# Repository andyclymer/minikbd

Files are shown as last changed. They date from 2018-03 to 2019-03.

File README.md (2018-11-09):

# MiniKbd

The MiniKbd is a USB device based on the [Adafruit Trinket M0](https://learn.adafruit.com/adafruit-trinket-m0-circuitpython-arduino) development board which is programmable with CircuitPython. The parts are [available for sale on Tindie](https://www.tindie.com/products/andyclymer/minikbd-little-diy-mechanical-keyboard-kit/), with build documentation and software samples available in this repo.

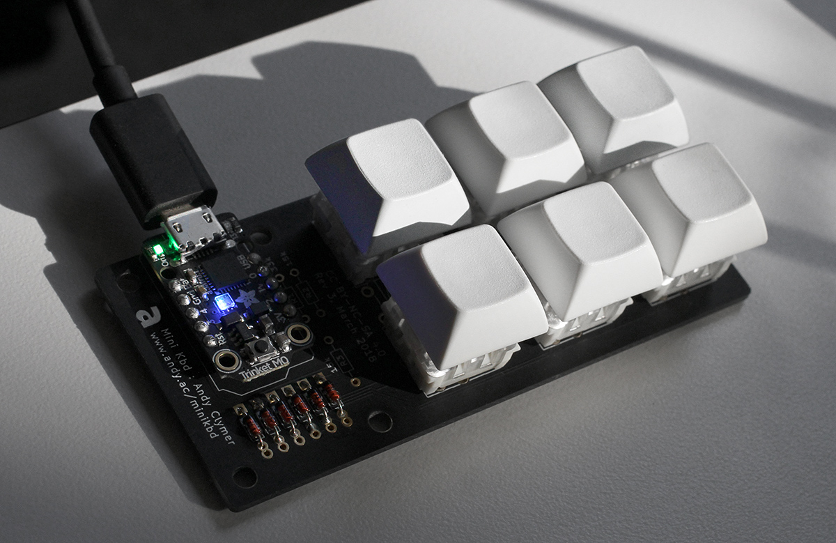
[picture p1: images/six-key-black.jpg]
MiniKbd


The MiniKbd is programmable with CircuitPython, each key can be easily customized to perform any combination of keystroke or mouse movement. When plugging it in over USB, your computer will recognize it as a “USB HID” (Human Interface Device), as if a keyboard or mouse had been plugged in. The keystrokes that are output by the MiniKbd can then be configured by editing the CircuitPython code running on the device.

The project came out of the idea of wanting a keyboard that simply had a larger set of arrow keys that I could position to the left side of my keyboard. [OSH Park](http://www.oshpark.com), the prototyping service that I use  to manufacture PCBs will always make boards in sets of three, so instead of having three of the same device I designed the MiniKbd to be built in three separate ways —

# Documentation and parts list

The MiniKbd is a DIY project, and I hope that you'll build one! Complete build documentation, parts list, and KiCad source files can be found in the [Hardware](./Hardware) directory of this repo, and code examples can be found inthe [Software](./Software) directory.

## Buying it
[The MiniKbd kit is available for sale on Tindie](https://www.tindie.com/products/andyclymer/minikbd-little-diy-mechanical-keyboard-kit/) if you'd like to build one (or two) for yourself!



# Build the MiniKbd in one of three layouts

[The build documentation can be found in the Hardware directory of this repo.](./Hardware)

### Layout #1: “Six Keyboard Keyswitches”

Six keyboard keys, with component footprints for the most popular Cherry MX, Cherry ML and Kalih Low Profile keyswitches. Choose keyswitches that are as clicky and springy as you wish.

Since the Trinket M0 only has five general purpose IO pins and this variation has six keyswitches, they are wired up as a matrix of three rows by two columns of keyswitches. I've written a simple library to read the keypresses of a small [button matrix](https://github.com/andyclymer/circuitpython_libs/tree/master/buttonMatrix) like this one.

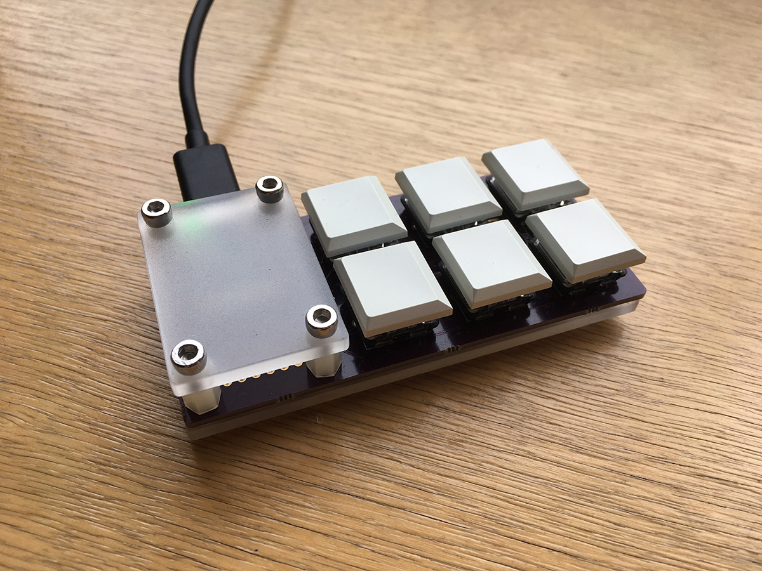
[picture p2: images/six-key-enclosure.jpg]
MiniKbd with six keyswitches


### Layout #2: “Two Rotary Encoders”

Whereas a “potentiometer” is the kind of knob designed to turn from 0 to 100% (like a volumne knob), its cousin the Rotary Encoder can freely turn continuously in either direction, clicking like a jog-dial as it turns (usually 12 or 24 clicks per rotation). With each click, the MiniKbd receives a signal that it's able to interpret to know whether it was turned clockwise or counterclockwise. Then, with each click, a keyboard command can be sent to the computer.

For instance, if the "z" and "x" keys are set up to zoom in and out in your drawing application, you can make one of the encoders into a zoom knob by having it type the letter "z" with each click in one direction, and the letter "x" in the other. 

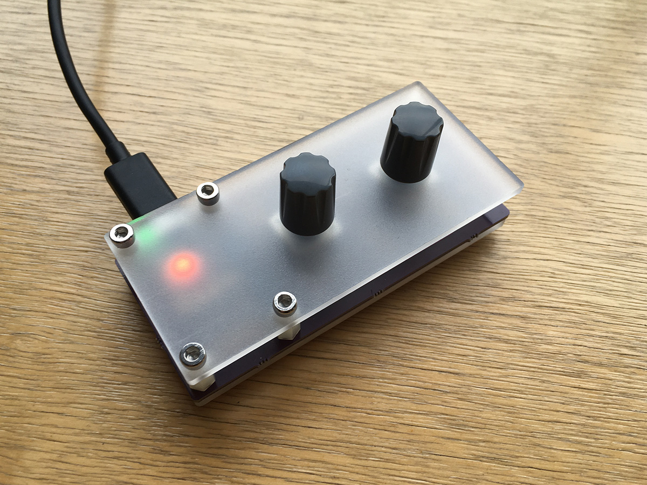
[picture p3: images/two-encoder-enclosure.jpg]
MiniKbd with two encoders

### Layout #3: “One rotary encoder and two keyboard keyswitches”

The best of both worlds, almost like a little mouse that only has a scroll wheel and two buttons for clicking.

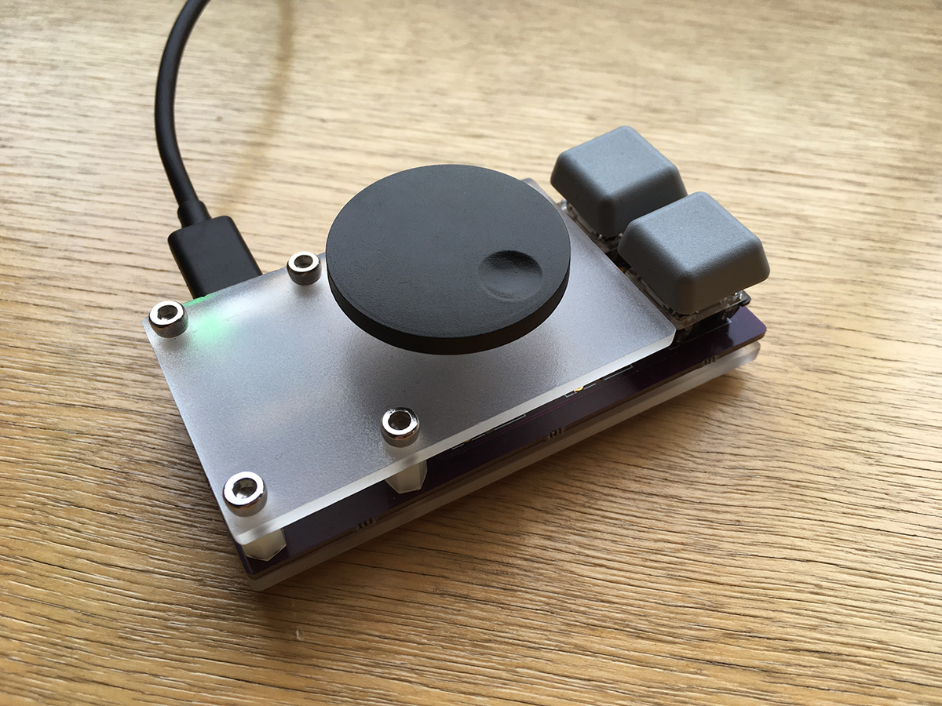
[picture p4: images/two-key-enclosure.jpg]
MiniKbd with one encoder and two keys


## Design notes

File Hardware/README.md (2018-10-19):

# MiniKbd Hardware

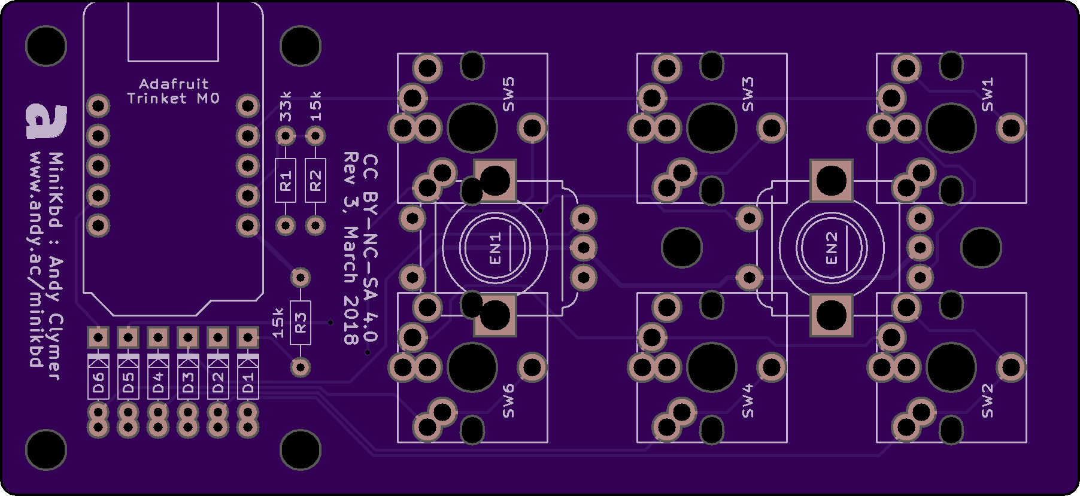
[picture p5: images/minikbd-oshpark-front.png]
minikbd-oshpark-front


The MiniKbd is designed to be built in one of three configurations:

- “Six keyboard keyswitches”
- “Two rotary encoders”
- “One rotary encoder and two keyboard keyswitches”

## Buying it
[The MiniKbd kit is available for sale on Tindie](https://www.tindie.com/products/andyclymer/minikbd-little-diy-mechanical-keyboard-kit/) if you'd like to build one (or two) for yourself! I'm selling the PCB, four sticker feet, and an optional set of hardware for use with the enclosure. The remaining parts will need to be sourced separately, but they can be found fairly easily from my guide below.

## Parts List
The full list of parts for each of the three configurations along with a buying guide can be found in the [Parts List](./PartsList.md) file in this directory.

## Building it
Build guides are available for all three configurations:
- [Build Doc — Six Keyboard Keyswitches](./Build-SixKeyswitches.md)
- [Build Doc — Two Rotary Encoders](./Build-TwoEncoders.md)
- [Build Doc — One Rotary Encoder and Two Keyboard Keyswitches](./Build-OneEncoderTwoSwitches.md)

## MiniKbd Enclosure
A very simple laser cut enclosure can be made with the plans in the [Enclosure](./Enclosure) directory. Files are available to send for laser cutting at Ponoko if you don't have access to your own laser cutter.

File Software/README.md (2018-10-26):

# MiniKbd Software

When you connect the MiniKbd (or rather, the Adafruit Trinket M0) to your computer you'll find that it mounts as a small ``CIRCUITPY`` drive. Each time the Trinket M0 is powered up or restarted it will run the ``main.py`` that it finds at the root level of its file system, so all of your code editing will start with this file. I've included a few preset Python scripts in this area of the repo that you can drop in and start using.

The Trinket M0 is a full 32-bit computer, but resources are scarce! With only 256k of storage, after embedding a slimmed down Python standard library there isn't much room left for your own code. If you don't think you'll need to use the MiniKbd on a Windows computer, you can also save some space by deleting the Windows driver from the Trinket's drive.

## Sample code

Each of the directories in this part of the repo have sample code that you can drag and drop to the root level of the Trinket's file system. As soon as the new files show up, the device should reboot and it will be in use right away.

## Before editing

It might be really helpful to use the Terminal on your computer to connect to the device as a serial console, so that you can see any `print` statements and error messages while you work with the code on your MiniKBD. To do this, have a look at Adafruit's recommendation for [connecting to the serial console](https://learn.adafruit.com/welcome-to-circuitpython/advanced-serial-console-on-mac-and-linux).

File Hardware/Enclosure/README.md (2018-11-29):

## Enclosure

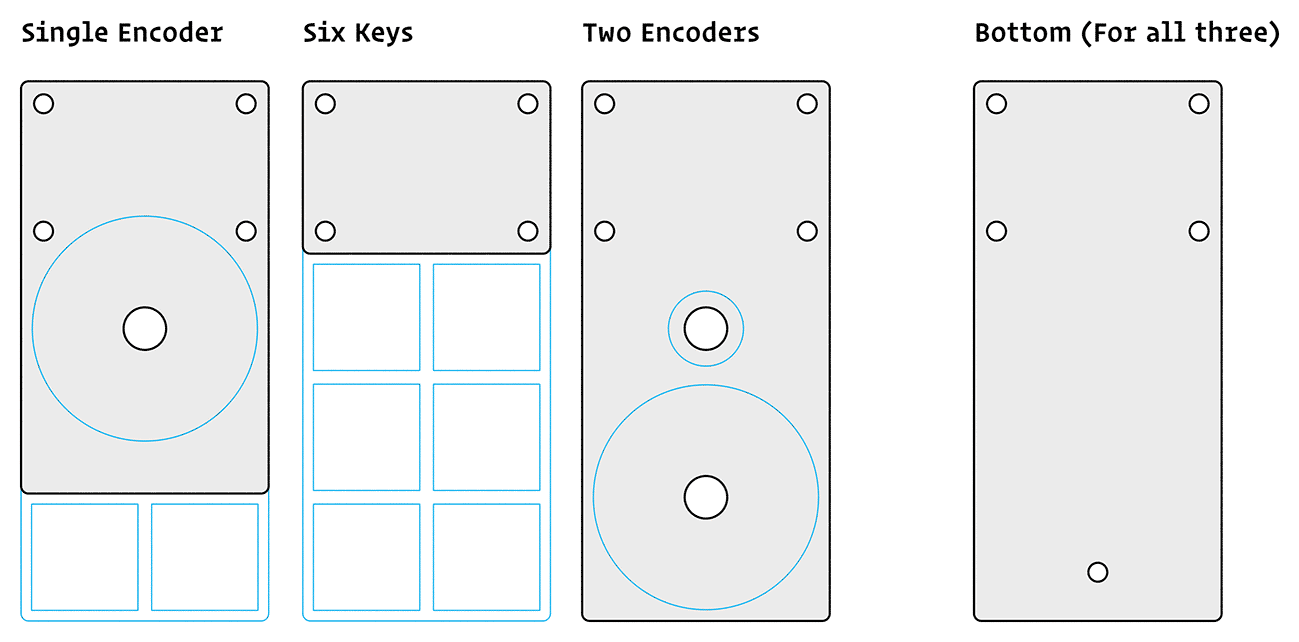
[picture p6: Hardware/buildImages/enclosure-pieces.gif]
enclosure


The MiniKbd doesn't need to be built in an enclosure, but at minumum I would highly suggest at least getting a set of small rubber bumper feet for the bottom so that it stays put and doesn't scratch up your desk. [Adafruit has a set of four](https://www.adafruit.com/product/550) if you're already ordering from them, as well as [Kiwi Electronics](https://www.kiwi-electronics.nl/siliconen-voetjes-voor-behuizingen-4-stuks) in The Netherlands, but I prefer the [3M SJ5312 Bumpon](https://www.amazon.com/gp/product/B000NG60SW/ref=oh_aui_detailpage_o00_s00?ie=UTF8&psc=1) because they're very small and grippy.

For the enclosure, I've laser cut parts in 1/8 inch (3mm) acrylic sheet, which can be avaialble from many sources. Files are available this directory, in the [Laser.pdf](./Laser.pdf). You won't want to completely obscure the LEDs on the top of the Trinket so I would recommend translucent acrylic if available. I like using the [Frosted Satin Ice](https://www.canalplastic.com/collections/plexi-sheets/products/0d010-df-frosted-satin-ice-acrylic-sheet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) that I buy at Canal Plastics in NYC, but I would encourage you to look for local options. 

Files are also prepared in this directory using templates from [Ponoko](https://www.ponoko.com/) where the enclosures can be ordered very cheaply. The files fit Ponoko’s smallest “P1” material size but the enclosure still only needs a small amount of material, feel free toa add your own art to the file before ordering.

In addition to the laser cut acrylic parts and the rubber bumper feet, you will also need:
- 4 × 8mm long M3 sized standoffs
- 5 × M3x8mm or 10mm screws
- 4 × M3x6mm screws
- 1 × M3 nut
- 5 × M3x1mm washers

Amazon and Ebay seem to be good places to buy these parts resonable price, I bought the [white Nylon m3 standoff assortment](https://www.amazon.com/gp/product/B01DK3905Y/ref=oh_aui_detailpage_o00_s00?ie=UTF8&psc=1) which is also available in [black](https://www.amazon.com/gp/product/B01E8JZWZ6/ref=ox_sc_sfl_title_14?ie=UTF8&psc=1&smid=A1Z1DJFHECM1GS), along with a small set of [M3 1mm nylon washers](https://www.amazon.com/gp/product/B01N45UFLG/ref=oh_aui_detailpage_o01_s00?ie=UTF8&psc=1). You can go nuts and get the same [stainless hex screws](https://www.amazon.com/gp/product/B01M3SFIAZ/ref=oh_aui_detailpage_o01_s00?ie=UTF8&psc=1) that I used for the top four screws of the enclosure.

The set of nylon hardware that I've linked to above only has 10mm long screws which will be too long, but you can very easily clip 2mm or so off of the screws that you use on the top of the enclosure.

### Build guide

#### 1)

Start with the bottom piece of the enclosure. Feed the five longer screws through, and temporarily cover the screw heads with tape.

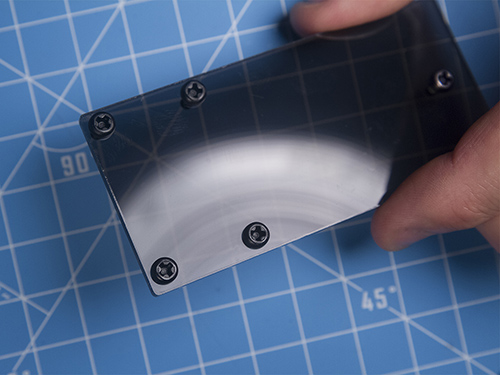
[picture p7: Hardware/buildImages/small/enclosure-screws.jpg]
Enclosure

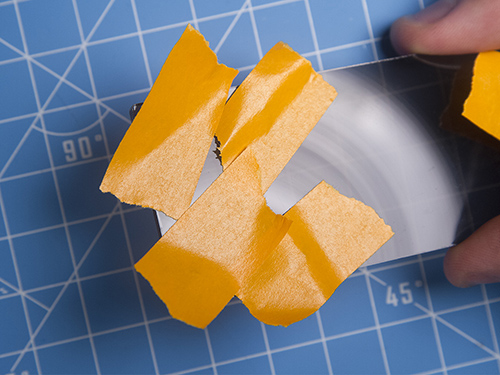
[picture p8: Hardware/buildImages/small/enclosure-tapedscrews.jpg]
Enclosure


#### 2)

Flip the bottom over so that the tape and screw heads are facing down (good thing the tape is holding it all together for now).

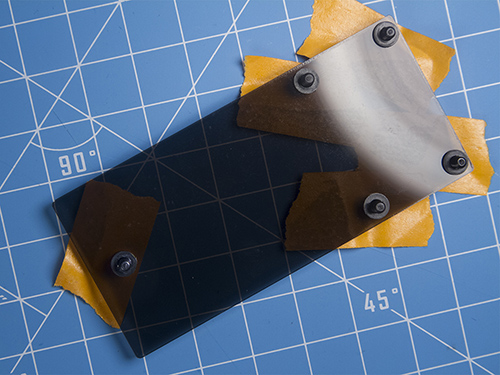
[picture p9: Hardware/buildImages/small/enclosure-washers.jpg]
Enclosure


Place the 1mm washers on all five screws. This will keep the MiniKbd circuit board spaced just slightly off of the enclosure, which should be enough room for the solder joints on the bottom of the board to keep from pressing down unevenly.

#### 3)

Keeping everything together, feed the MiniKbd circuit board on to the five screws and washers.

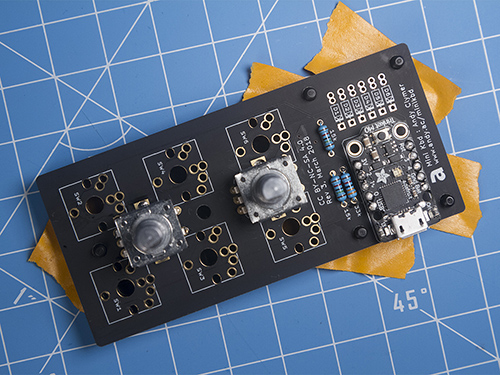
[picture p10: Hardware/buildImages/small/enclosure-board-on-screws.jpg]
Enclosure


#### 5)

Screw on the four spacers. You can start by tightening them by hand, then once the screw is started you can remove the tape and finish with a screwdriver. No need to over-tighten!

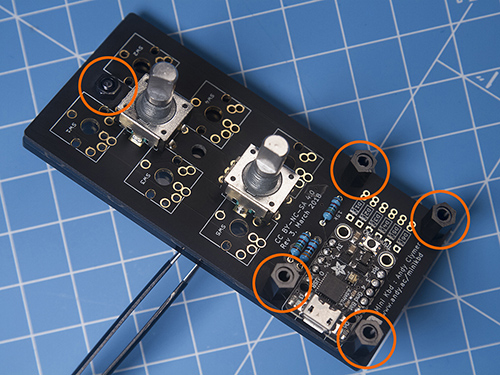
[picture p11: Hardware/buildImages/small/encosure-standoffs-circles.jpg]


Attach the nut to the fifth screw on the other end of the board. You might need a set of pliers to hold the nut while you attach the screw, or you might be able to just hold the nut by presing straight down with a finger.

#### 7)

Finish by attaching the top enclosure piece with four shorter screws.

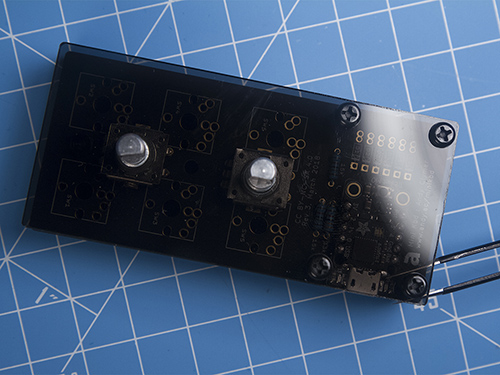
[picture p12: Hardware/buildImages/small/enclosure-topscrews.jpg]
Enclosure


Here's what the full stackup should look like:

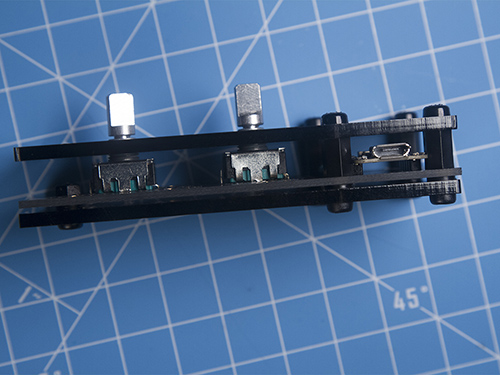
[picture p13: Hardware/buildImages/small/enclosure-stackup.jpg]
Enclosure


#### 8)

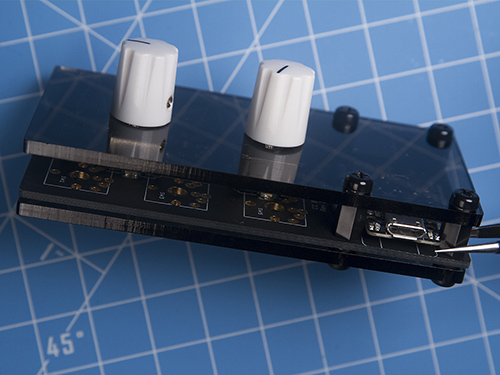
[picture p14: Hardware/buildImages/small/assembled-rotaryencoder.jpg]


Add the knobs or keycaps (depending on the build), and the sticker feet to the bottom of the MiniKbd and you're ready to go!

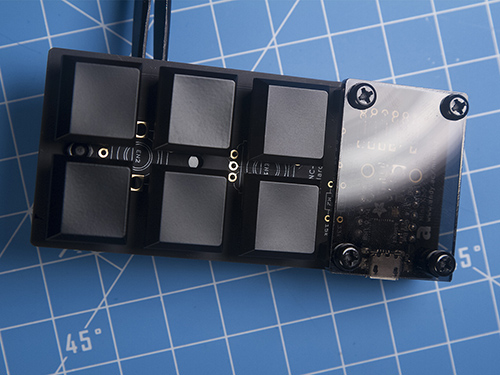
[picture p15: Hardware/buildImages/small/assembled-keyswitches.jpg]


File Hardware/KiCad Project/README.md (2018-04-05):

# MiniKbd Hardware

minikbd-oshpark-front

The MiniKbd is designed to be built in one of three configurations:

- “Six keyboard keyswitches”
- “Two rotary encoders”
- “One rotary encoder and two keyboard keyswitches”

## Buying it
Build one yourself! A batch of MiniKbd circuit boards is currently being made and once they've arrived in mid-April I'll have some for sale for around $6 each. Then, you can collect the parts listed below and build your own (or all three!)

## Parts List
Since there's more than one way to build the MiniKbd, not all component footprints on the MiniKbd PCB need to be filled depending on the variation you choose to build. Here are the parts lists for all three versions:

#### “Six Keyboard Keyswitches”
Qty | Component | Note
:---:|---|---
1 | Adafruit Trinket M0 | *The black “M0” and not the blue “3V” or “5V” variations of the Trinket*
6 | Keyswitches and keycaps | *Cherry MX, Cherry ML or Kailh Low Profile keyswitches will work*
6 | 1N4148 Small Signal Diodes | 
— | Various enclosure parts | *Optional but recommended, see notes below*

#### “Two Rotary Encoders”
Qty | Component | Note
:---:|---|---
1 | Adafruit Trinket M0 | *The black “M0” and not the blue “3V” or “5V” variations of the Trinket*
2 | Rotary Encoders | *2-bit quadrature, with a common footprint from the Bourns PEC11R series*
2 | 33kΩ Resistors | *1/8 watt*
1 | 15kΩ Resistors | *1/8 watt*
— | Various enclosure parts | *Optional but recommended, see notes below*

#### “One rotary encoder and two keyboard keyswitches”
Qty | Component | Note
:---:|---|---
1 | Adafruit Trinket M0 | *The black “M0” and not the blue “3V” or “5V” variations of the Trinket*
2 | Keyswitches and keycaps | *Cherry MX, Cherry ML or Kailh Low Profile keyswitches will work*
2 | 1N4148 Small Signal Diodes | 
1 | Rotary Encoder | *2-bit quadrature, with a common footprint from the Bourns PEC11R series*
— | Various enclosure parts | *Optional but recommended, see notes below*

## Buying Parts

#### Adafruit Trinket M0
The Trinket M0 can be purchased directly from the manufacturer, Adafruit, and can be found on other online shops for about $9 or €9. The most important consideration for this project is to buy the black colored Trinket “M0”, and *not* the blue “3V” or “5V” variations.

Retailer | Part number
---|---
Adafruit | Adafruit Trinket M0 [#3500](https://www.adafruit.com/product/3500)
Mouser | Adafruit Trinket M0 [485-3500](https://www.mouser.com/ProductDetail/Adafruit/3500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)
Floris | Adafruit Trinket M0 [#1947](https://www.floris.cc/shop/en/home/1947-adafruit-trinket-m0-for-use-with-circuitpython-arduino-ide.html)

#### Keyswitches and keycaps
There's an incredibly wide range of options when choosing keyswitches and keycaps, and the MiniKbd footprint works with the popular Cherry MX, Cherry ML and Kailh Low Profile keyswitches. Do a little bit of research first, the popular Cherry MX switches come in a wide array of options for [different levels of force or clickyness](http://www.keyboardco.com/blog/index.php/2012/12/an-introduction-to-cherry-mx-mechanical-switches/). I think the best advice I have is to order a few and see what you like. I prefer the [“Tactile Brown” Kailh Low Profile keyswitches from Novel Keys](https://novelkeys.xyz/products/kailh-low-profile-switches) and don't forget to order the [keycaps](https://novelkeys.xyz/collections/keycaps/products/kailh-low-profile-keycaps-blank). For the Cherry MX switches you have a wide range of options for keycaps from [Pimp My Keyboard](https://pimpmykeyboard.com/).

Retailer | Part number
---|---
Novel Keys | [Kailh Low Profile Keyswitches](https://novelkeys.xyz/products/kailh-low-profile-switches) and [Kailh Low Profile Keycaps](https://novelkeys.xyz/collections/keycaps/products/kailh-low-profile-keycaps-blank)
Mouser | [Cherry MX search results](https://www.mouser.com/Electromechanical/Switches/_/N-5g2h?Keyword=cherry+mx&FS=True) with lots of options

#### 1N4148 Small Signal Diodes
An extremely common part, one diode is required for each keyswitch.

Retailer | Part number
---|---
Adafruit | [#1641](https://www.adafruit.com/product/1641) for a 10 pack
Mouser | [512-1N4148](https://www.mouser.com/ProductDetail/ON-Semiconductor-Fairchild/1N4148?qs=sGAEpiMZZMudZehw8RjeZWbu6z6oTQTL)
Tayda Electronics | [A-157](https://www.taydaelectronics.com/1n4148-switching-signal-diode.html) for 1¢ each!

#### Rotary Encoders
You will need a standard *2-bit quadrature* encoder, which means that with each click as you rotate it will send a [pattern of pulses on two pins](https://en.wikipedia.org/wiki/Rotary_encoder) (and not a “gray code” encoder which uses three pins). I went with a common “footprint” for the rotary encoder which you would find in the Bourns PEC11R series, but not all encoders out there will fit. Any encoders with a lighted shaft would have extra pins that won't fit on the MiniKbd circuit board. Also note that the rotary encoders from Floris have the correct footprint, however the shaft would be too short to fit with the enclosure, but it would work fine without the enclosure top. 

Retailer | Part number
---|---
Adafruit | [#377](https://www.adafruit.com/product/377) comes with a simple knob
Mouser |  [PEC11R-4215F-S0024](https://www.mouser.com/ProductDetail/Bourns/PEC11R-4215F-S0024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)
Floris | [#567](https://www.floris.cc/shop/en/knobs-buttons-joysticks/567-rotary-encoder-.html?search_query=encoder&results=12) will work but will be too short for the enclosure

Also, don't forget to order a knob for the encoder, the recommended Bourns encoder would need a “D-shaft” knob.

Retailer | Part number
---|---
Adafruit | [#2055](https://www.adafruit.com/product/2055) is a larger 35mm knob, it won't sit flush with the enclosure but still looks nice
Thonk | [Davies 1900h clone D-shaft](https://www.thonk.co.uk/shop/1900h-d/)
DJ Tech Tools | [Chroma Caps](https://store.djtechtools.com/products/chroma-caps-knobs-and-faders)

#### Resistors
The “Two Encoders” build will need three resistors, but the two other builds won’t require any. The smaller and very common 1/8 Watt metal film resistors will fit nicely.

Retailer | Part number
---|---
Tayda Electronics | [A-3813](https://www.taydaelectronics.com/resistors/1-8w-metal-film-resistors/r-33k-ohm-1-8w-1-metal-film-resistor.html) for the 33k ohm (×2), and [A-3803](https://www.taydaelectronics.com/resistors/1-8w-metal-film-resistors/r-15k-ohm-1-8w-1-metal-film-resistor.html) for the 15k ohm (×1)
Mouser | **TK**

#### Enclosure parts

The enclosure consists of a variety of pieces, all of which are optional or can be substituted:
- Laser cut parts from acrylic sheet
- 4 × 8mm long M3 sized standoffs (5 or 6mm long should work)
- 9 × M3x6mm screws
- 1 × M3 nut
- 5 × M3x1mm washers
- 4 × rubber bumper feet

The MiniKbd doesn't need to be built in an enclosure, but at minumum I would highly suggest at least getting a set of small rubber bumper feet for the bottom so that it stays put and doesn't scratch up your desk. [Adafruit has a set of four](https://www.adafruit.com/product/550) if you're already ordering from them, but I prefer the [3M SJ5312 Bumpon](https://www.amazon.com/gp/product/B000NG60SW/ref=oh_aui_detailpage_o00_s00?ie=UTF8&psc=1) because they're very small and grippy.

For the enclosure, I've laser cut parts in 1/8 inch (3mm) acrylic sheet, which can be avaialble from many sources. Files are available in the Enclosure folder of the repo. You won't want to completely obscure the LEDs on the top of the Trinket so I would recommend translucent acrylic if available. I like using the [Frosted Satin Ice](https://www.canalplastic.com/collections/plexi-sheets/products/0d010-df-frosted-satin-ice-acrylic-sheet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) that I buy at Canal Plastics in NYC, but I would encourage you to look for local options. Laser cutting might also be able to be ordered from [Ponoko](https://www.ponoko.com/).

Amazon and Ebay seem to be good places to buy a variety of standoffs and screws at a resonable price, I use the [white Nylon m3 standoff assortment](https://www.amazon.com/gp/product/B01DK3905Y/ref=oh_aui_detailpage_o00_s00?ie=UTF8&psc=1) which is also available in [black](https://www.amazon.com/gp/product/B01E8JZWZ6/ref=ox_sc_sfl_title_14?ie=UTF8&psc=1&smid=A1Z1DJFHECM1GS), along with a small set of [M3 1mm nylon washers](https://www.amazon.com/gp/product/B01N45UFLG/ref=oh_aui_detailpage_o01_s00?ie=UTF8&psc=1). You can go nuts and get the same [stainless hex screws](https://www.amazon.com/gp/product/B01M3SFIAZ/ref=oh_aui_detailpage_o01_s00?ie=UTF8&psc=1) that I used for the top four screws of the enclosure.

## Building it
*Working on a build guide!*

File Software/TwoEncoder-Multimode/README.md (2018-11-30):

# MiniKbd Software — Multimode

This demo shows one way to use the Two Encoder build of the MiniKbd in more than one mode.

A more detailed breakdown of how the Two Encoder code works can be found with the TwoEncoder-Keyboard example, I would recommend becoming familiar with that demo first.

Pressing the left encoder button switches between modes. Each mode lights the RGB LED in a different color, and the callbacks are then written to fire off different keyboard combinations depending on the mode.

In this example, the first mode lights the LED greenish-blue and makes the encoder dials work as audio controls. The second mode lights the LED red and changes the encoders to work as shortcuts for a separate application.

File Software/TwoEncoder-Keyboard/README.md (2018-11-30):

# MiniKbd Software — Two Encoder Keyboard

This is the basic starting point for using two rotatry encoders as a keyboard.

As the rotary encoders turn, each click of the encoder triggers a keyboard command. This is really useful for the kinds of keystrokes that you might normally click repeatedly — the default here has one encoder typing "z" in one direction and "x" in the other which already map to the "Zoom In" and "Zoom Out" commands in the design application that I use. Instant zoom dial. Another idea could be to type the keyboard command for "Volume Up" with each click in one direction and "Volume Down" in another direction, I've provided this as a separate example in the same repo.

### How to use this sample code

Copy the `main.py` and `encoder.py` to the root level of your Trinket M0. The `main.py` code is run every time the Trinket reboots, and it imports code from the `encoder` library.

Before editing, I have some general advice for working with the MiniKBD one level back in the [Software](../) directory of this repo.

The `main.py` script contains the code that you'll edit to customize how the device works. Space is limited on the Trinket M0 so I'm providing a commented version of the code here to explain how it works (the comments would take up valuable space that you should be using for your code!)

```python
import board
import adafruit_dotstar as dotstar
from adafruit_hid.keyboard import Keyboard
from adafruit_hid.keycode import Keycode
from digitalio import DigitalInOut, Direction, Pull
from analogio import AnalogIn
import time
import random

# Import the encoder library that I've provided
from encoder import Encoder

# Create an object for the RGB "Dotstar" LED on the Trinket
# and set the RGB value for Black, to get started.
dot = dotstar.DotStar(board.APA102_SCK, board.APA102_MOSI, 1, brightness=0.1)
dot[0] = (0, 0, 0)

# Create a new Keyboard object. We'll send keyboard commands to this later.
kbd = Keyboard()

# Add a small 1/10 sec delay between button presses, otherwise clicking the encoder button might hit the callback several times
# This function will be checked before the button callback sends a keycode to the computer.
prevTurn = time.monotonic()
def fastClick():
	global prevTurn
	now = time.monotonic()
	diff = now - prevTurn
	prevTurn = now
	if diff < 0.1:
		return True
	return False

# Encoder callbacks

# Each time the rotary encoder moves one notch "up" or one notch "down" these functions are called
# You'll edit these: replace the print statements with whatever you want the device to do when
# the rotary encdoer is rotated.

# Customize the keycodes to change how the device functions.
# Each key has a number, and one keycode. The full list of keycodes can be found here:
# https://circuitpython.readthedocs.io/projects/hid/en/latest/api.html#adafruit-hid-keycode-keycode

# The first encoder will type the letter "z" with each click when rotated in one direction,
# and the letter "x" when rotated in the other direction. In the design appliaction I use,
# these two keystrokes will zoom in and zoom out of the document. Nice!
# They also set the LED to be a random reddish color when rotated in one direction, and a
# random blueish color in the other direction.

def enc1Up():
	print("enc-1-up")
	dot[0] = (255, random.randint(0, 255), 0)
	kbd.press(Keycode.Z)
	kbd.release_all()
	
def enc1Down():
	print("enc-1-down")
	dot[0] = (0, random.randint(0, 255), 255)
	kbd.press(Keycode.X)
	kbd.release_all()

# Then, the other encoder types the left bracket when rotated in one direction, and the right bracket
# when rotated the other direction. Again, in the application I use, these step up and down through
# the drawing layers. Between these two encoders I have a nice little interface!

def enc2Up():
	print("enc-2-up")
	dot[0] = (255, random.randint(0, 255), 0)
	kbd.press(Keycode.LEFT_BRACKET)
	kbd.release_all()

def enc2Down():
	print("enc-2-down")
	dot[0] = (0, random.randint(0, 255), 255)
	kbd.press(Keycode.RIGHT_BRACKET)
	kbd.release_all()

# The encoders also work like buttons when they're pressed down. The first encoeder (the one that was
# zooming in and out for me) will type Command-Zero which resets the zoom to 100%. The other
# encoder types Command-A when clicked down.
# Before returning the keycode, it calls the fastClick() function which will return True if 
# the button had been pressed down 1/10 sec previously.

def button1():
	if not fastClick():
		print("enc-1-button")
		# Press a combination of the command key and zero
		kbd.press(Keycode.GUI, Keycode.ZERO)
		kbd.release_all()
	
def button2():
	if not fastClick():
		print("enc-2-button")
		kbd.press(Keycode.GUI, Keycode.A)
		kbd.release_all()

# Make a new objects for the rotary encoders. These take care of watching for changes in state
# to the encoder, it figures out if the encoder was rotating "up" or "down", and then calls
# the callback functions above.

e1 = Encoder(board.D4, board.D3, upCallback=enc1Up, downCallback=enc1Down)
e2 = Encoder(board.D1, board.D0, upCallback=enc2Up, downCallback=enc2Down)

# The two encoders have buttons when they're clicked down, and they share an analog input pin.
# This will be explained a little bit more below.
buttonPin = AnalogIn(board.D2)

# The main loop for the script. Now that all of the callback functions are defined, and the
# objects are made, this script will continuously ask the Encoder objects to update and check
# for a state change. When the state does change, the objects will call the callback functions 
# at the top of this script.

while True:
	
  # Check both encoders for a change
	e1.update()
	e2.update()
	
	# The two encoder buttons share one analog input pin (because only one pin is left!)
	# The buttons pass through resistors of different values, so buy comparing the analog
	# voltage we're able to see which buttons are being held down.
	v = buttonPin.value
	if 65535 > v > 54500:
		b1 = False
		b2 = False
	elif 54500 > v > 38500:
		b1 = True
		b2 = False
	elif 38500 > v > 29400:
		b1 = False
		b2 = True
	elif v < 29400:
		b1 = True
		b2 = True
    
	# Now that we know which buttons are held down, call their callback functions
	if b1:
		button1()
	if b2:
		button2()

```

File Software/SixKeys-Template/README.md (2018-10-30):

# MiniKbd Software — Six Keyswitches

This is the simplest way to get started with the "Six Keyswitches" build, it provides an easy way to assign a single keystroke to each key. Other more complex examples are also available.

### How to use this sample code

Copy the `main.py` and `buttonMatrix.py` to the root level of your Trinket M0. The `main.py` code is run every time the Trinket reboots, and it imports code from the `buttonMatrix` library.

Before editing, I have some general advice for working with the MiniKBD one level back in the [Software](../) directory of this repo.

The basic principle is that you will want to edit the `buttonIDtoKeycode` dictionary in the `main.py` to customize the keyboard.

```python
buttonIDtoKeycode = {
    1: Keycode.SHIFT,
    2: Keycode.RIGHT_ARROW,
    3: Keycode.UP_ARROW,
    4: Keycode.DOWN_ARROW,
    5: Keycode.SHIFT,
    6: Keycode.LEFT_ARROW}
 ```
Each key is assigned a keycode in this dictionary. A full list of keycodes can be found in the [CircuitPython keycode docs](https://circuitpython.readthedocs.io/projects/hid/en/latest/api.html). When looking directly at the keyboard, the keys are numbered in the following arrangement:
 
 ```
 ┏━┷┷━┯━━━┯━━━┯━━━┓
 ┃°  °│ 5 │ 3 │ 1 ┃
 ┃    ├───┼───┼───┨
 ┃°  °│ 6 │ 4 │ 2 ┃
 ┗━━━━┷━━━┷━━━┷━━━┛
 
```

The `main.py` script contains the code that you'll edit to customize how the device works. Space is limited on the Trinket M0 so I'm providing a commented version of the code here to explain how it works (the comments would take up valuable space that you should be using for your code!)

```python
import board
from digitalio import DigitalInOut, Direction, Pull
import adafruit_dotstar as dotstar
from adafruit_hid.keyboard import Keyboard
from adafruit_hid.keycode import Keycode
from adafruit_hid.keyboard_layout_us import KeyboardLayoutUS

# Import the MiniKbdButtons library that I've provided
# All of the code that deals with reacting to key changes is kept in here
from miniKbdButtons import MiniKbdButtons

# Create an object for the RGB "Dotstar" LED on the Trinket
# and set the RGB value for Black, to get started.
dot = dotstar.DotStar(board.APA102_SCK, board.APA102_MOSI, 1, brightness=0.2)
dot[0] = (0, 0, 0)

# Create a new Keyboard object. We'll send keyboard commands to this later.
kbd = Keyboard()
kbdLayout = KeyboardLayoutUS(kbd)

# Customize these keycodes to change how the device functions.
# Each key has a number, and one keycode. The full list of keycodes can be found here:
# https://circuitpython.readthedocs.io/projects/hid/en/latest/api.html#adafruit-hid-keycode-keycode
buttonIDtoKeycode = {
	1: Keycode.ONE,
	2: Keycode.TWO,
	3: Keycode.THREE,
	4: Keycode.FOUR,
	5: Keycode.FIVE,
	6: Keycode.SIX}

# Key callbacks

# These functions are called when a key is pressed down and when a key is released.
# You'll edit these: replace the print statements with whatever you want the device to do when
# the keys are pressed or released.

# All of the buttons use the same callback functions, but the function receives the ID number of
# the key so you can program the callbacks to do different things depending on which key is held down.
# Another helpful thing is you'll also be given a list of othersDown which contains the button IDs
# for any other buttons that are also being held down.

# This simple example takes the buttonID and finds the keycode in the buttonIDtoKeycode dictionary
# (shown above) and then tells the keyboard object to press this keycode.

def buttonDownCallback(buttonID, othersDown):
    # When a key is pressed, find its keycode in the buttonIDtoKeycode dictionary,
    # and tell the keyboard object to press this keycode.
	kbd.press(buttonIDtoKeycode[buttonID])
	dot[0] = (255, 0, 0) # Turn the LED to be 100% Red and 0% Green and Blue
	print("Button _down_", buttonID, othersDown)

def buttonUpCallback(buttonID):
    # When a key has been lifted, find its keycode again in the buttonIDtoKeycode dictionary
    # and tell the keyboard to release that key. Without doing this, the key would still be held down!
	kbd.release(buttonIDtoKeycode[buttonID])
	dot[0] = (0, 0, 0)
	print("Button ^UPUP^", buttonID)

# Create a new MiniKbdButtons object, which we'll use in just a moment...
ButtonMatrix = MiniKbdButtons(
	keyDownCallback=buttonDownCallback, 
	keyUpCallback=buttonUpCallback)

# The main loop for the script. Now that all of the callback functions are defined, and the
# objects are made, this script will continuously ask the ButtonMatrix object to update and check
# for a state change. When the state does change, the objects will call the callback functions 
# at the top of this script.
while True:
	ButtonMatrix.update()
```

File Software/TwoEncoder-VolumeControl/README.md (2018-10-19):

# MiniKbd Software — Volume Control

For use with the “Two Rotary Encoders” build variation. One knob advances the track forward and back, the other knob adjusts the volume. This script builds off of the [TwoEncoderKeyboard](../TwoEncoderKeyboard) sample code.

On the Mac, turning the volume knob slowly increments the level with fine-grained control, the equivalent of holding down the “Option” key while pressing the volume keys on the keyboard. A quick turn increments the volume at a faster rate.

Pressing either knob will send the “Play/Pause” keystroke.

### How to use this sample code

Copy the `main.py` and `encoder.py` to the root level of your Trinket M0. The `main.py` code is run every time the Trinket reboots, and it imports code from the `encoder` library.

Before editing, I have some general advice for working with the MiniKBD one level back in the [Software](../) directory of this repo.

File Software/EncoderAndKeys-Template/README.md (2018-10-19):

# MiniKbd Software — One Encoder and Two Keys

This is the basic starting point for code that works with the build option of one rotary encoder and two keyboard keys.

### How to use this sample code

Copy the `main.py`, `encoder.py` and `buttonMatrix.py` to the root level of your Trinket M0. The `main.py` code is run every time the Trinket reboots, and it imports code from the `encoder` and `buttonMatrix` libraries.

Before editing, I have some general advice for working with the MiniKBD one level back in the [Software](../) directory of this repo.

The `main.py` script contains the code that you'll edit to customize how the device works. Space is limited on the Trinket M0 so I'm providing a commented version of the code here to explain how it works (the comments would take up valuable space that you should be using for your code!)

```python
import board

# Import the Encoder and ButtonMatrix libraries that I've provided
from encoder import Encoder
from buttonMatrix import ButtonMatrix

# Encoder callbacks
# Each time the rotary encoder moves one notch "up" or one notch "down" these functions are called
# You'll edit these: replace the print statements with whatever you want the device to do when
# the rotary encdoer is rotated.

def rotatedUp():
	print("Up!")

def rotatedDown():
	print("Down!")

# Key callbacks
# These functions are called when a key is pressed down, 
# when a key is released, and when a key is held down for a length of time.
# You'll edit these: replace the print statements with whatever you want the device to do when
# the keys are pressed or released.
#   An info dictionary is passed along with it, with some helpful data:
#     'buttonID' = 1 or 2, the key number
#     'repeating' = True/False
#     'holdTime' = How long the key has been held down for
#     'othersDown' = A list of other buttonIDs that were already held down when this one was pressed

def buttonDownCallback(info):
	print("Button %s down" % info["buttonID"])

def buttonUpCallback(info):
	print("Button %s down" % info["buttonID"])

def buttonHoldCallback(info):
	print("Button %s down" % info["buttonID"])

# In the "One Encoder and Two Keyboard Keys" build setup, key number 1 is connected to
# pins D0 and D2, and key number 2 is connected to pins D1 and D2. They're wired in a matrix: 
# a signal is applied to both keys through D2 and the MiniKBD can sense which key(s) are held 
# down by checkingthe inputs of D0 and D1.

buttonMap = [
	dict(sendPinName="D0", receivePinName="D2", buttonID=1),
	dict(sendPinName="D1", receivePinName="D2", buttonID=2)]

# Make a new ButtonMatrix object for these two keys. This takes care of checking the state of 
# the keys and it will call the button callback functions above when the state changes.

Matrix = ButtonMatrix(
	buttonMap, 
	keyDownCallback=buttonDownCallback,
	keyUpCallback=buttonUpCallback,
	keyHoldCallback=buttonHoldCallback,
	holdDelayTime=1,
	holdRepeatTime=0.1)

# Make a new object for the rotary encoder. This takes care of watching for changes in state
# to the encoder, it figures out if the encoder was rotating "up" or "down", and then calls
# the callback functions above.

Encoder = Encoder(board.D3, board.D4, upCallback=rotatedUp, downCallback=rotatedDown)

# The main loop for the script. Now that all of the callback functions are defined, and the
# objects are made, this script will continuously ask the Encoder and Matrix objects to update
# and check for a state change. When the state does change, the objects will call the callback
# functions at the top of this script.

while True:
	Encoder.update()
	Matrix.update()
  
  ```

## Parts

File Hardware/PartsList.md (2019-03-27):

# MiniKbd Parts List

Since there's more than one way to build the MiniKbd, not all component footprints on the MiniKbd PCB need to be filled depending on the variation you choose to build. Here are the parts lists for all three versions:

#### “Six Keyboard Keyswitches”
Qty | Component | Note
:---:|---|---
1 | Adafruit Trinket M0 | *The black “M0” and not the blue “3V” or “5V” variations of the Trinket*
6 | Keyswitches and keycaps | *Cherry MX, Cherry ML or Kailh Low Profile keyswitches will work*
6 | 1N4148 Small Signal Diodes | 
— | Various enclosure parts | *Optional but recommended, see notes below*

#### “Two Rotary Encoders”
Qty | Component | Note
:---:|---|---
1 | Adafruit Trinket M0 | *The black “M0” and not the blue “3V” or “5V” variations of the Trinket*
2 | Rotary Encoders | *2-bit quadrature, with a common footprint from the Bourns PEC11R series*
1 | 33kΩ Resistors | *1/4 watt*
2 | 15kΩ Resistors | *1/4 watt*
— | Various enclosure parts | *Optional but recommended, see notes below*

#### “One rotary encoder and two keyboard keyswitches”
Qty | Component | Note
:---:|---|---
1 | Adafruit Trinket M0 | *The black “M0” and not the blue “3V” or “5V” variations of the Trinket*
2 | Keyswitches and keycaps | *Cherry MX, Cherry ML or Kailh Low Profile keyswitches will work*
2 | 1N4148 Small Signal Diodes | 
1 | Rotary Encoder | *2-bit quadrature, with a common footprint from the Bourns PEC11R series*
— | Various enclosure parts | *Optional but recommended, see notes below*

## Buying Parts

#### Adafruit Trinket M0
The Trinket M0 can be purchased directly from the manufacturer, Adafruit, and can be found on other online shops for about $9 or €9. The most important consideration for this project is to buy the black colored Trinket “M0”, and *not* the blue “3V” or “5V” variations.

Retailer | Part number
---|---
Adafruit (US) | Adafruit Trinket M0 [#3500](https://www.adafruit.com/product/3500)
Mouser | Adafruit Trinket M0 [485-3500](https://www.mouser.com/ProductDetail/Adafruit/3500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)
Floris (NL) | Adafruit Trinket M0 [#1947](https://www.floris.cc/shop/en/home/1947-adafruit-trinket-m0-for-use-with-circuitpython-arduino-ide.html)
Kiwi (NL) | Adafruit Trinket M0 [ADA-3500](https://www.kiwi-electronics.nl/arduino-trinket-m0?search=adafruit%20trinket%20m0)

#### Keyswitches and keycaps
There's an incredibly wide range of options when choosing keyswitches and keycaps, and the MiniKbd footprint works with the popular Cherry MX, Cherry ML and Kailh Low Profile keyswitches. Do a little bit of research first, the popular Cherry MX switches come in a wide array of options for [different levels of force or clickyness](http://www.keyboardco.com/blog/index.php/2012/12/an-introduction-to-cherry-mx-mechanical-switches/). I think the best advice I have is to order a few and see what you like. 

I prefer the [“Tactile Brown” Kailh Low Profile keyswitches from Novel Keys](https://novelkeys.xyz/products/kailh-low-profile-switches) and don't forget to order the [keycaps](https://novelkeys.xyz/collections/keycaps/products/kailh-low-profile-keycaps-blank). 

For larger full-height keyswitches, I like using [Gateron Silent Brown](https://novelkeys.xyz/collections/switches/products/gateron-silent-switches?variant=19441364303965) which are also tactile so that you can feel when you've made a click, but are far less noisy than most other keyswitches. These switches can use the same keycaps as the popular Cherry MX switches, and a wide range of keycap options are availble from [Pimp My Keyboard](https://pimpmykeyboard.com/sale-items/blank-key-packs/), I prefer the "DSA" profile keycaps.

Retailer | Part number
---|---
Novel Keys | [Kailh Low Profile Keyswitches](https://novelkeys.xyz/products/kailh-low-profile-switches) and [Kailh Low Profile Keycaps](https://novelkeys.xyz/collections/keycaps/products/kailh-low-profile-keycaps-blank)
Novel Keys | [Gateron Silent Brown Keyswitches](https://novelkeys.xyz/collections/switches/products/gateron-silent-switches?variant=19441364303965) and [DSA Profile Keycaps](https://pimpmykeyboard.com/dsa-1-space-pack-of-10/)
Mouser | [Cherry MX search results](https://www.mouser.com/Electromechanical/Switches/_/N-5g2h?Keyword=cherry+mx&FS=True) with lots of options

#### 1N4148 Small Signal Diodes
An extremely common part, one diode is required for each keyswitch.

Retailer | Part number
---|---
Adafruit (US) | [#1641](https://www.adafruit.com/product/1641) for a 10 pack
Mouser | [512-1N4148](https://www.mouser.com/ProductDetail/ON-Semiconductor-Fairchild/1N4148?qs=sGAEpiMZZMudZehw8RjeZWbu6z6oTQTL)
Tayda Electronics (US) | [A-157](https://www.taydaelectronics.com/1n4148-switching-signal-diode.html) for 1¢ each!
Kiwi (NL) | [KW-1524](https://www.kiwi-electronics.nl/1n4148-diode-10-stuks)

#### Rotary Encoders
You will need a standard *2-bit quadrature* encoder, which means that with each click as you rotate it will send a [pattern of pulses on two pins](https://en.wikipedia.org/wiki/Rotary_encoder) (and not a “gray code” encoder which uses three pins). I went with a common “footprint” for the rotary encoder which you would find in the Bourns PEC11R series, but not all encoders out there will fit. Any encoders with a lighted shaft would have extra pins that won't fit on the MiniKbd circuit board. Also note that the rotary encoders from Floris have the correct footprint, however the shaft would be too short to fit with the enclosure, but it would work fine without the enclosure top. 

Retailer | Part number
---|---
Adafruit (US) | [#377](https://www.adafruit.com/product/377) comes with a simple knob
Mouser |  [PEC11R-4215F-S0024](https://www.mouser.com/ProductDetail/Bourns/PEC11R-4215F-S0024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)
Floris (NL) | [#567](https://www.floris.cc/shop/en/knobs-buttons-joysticks/567-rotary-encoder-.html?search_query=encoder&results=12) will work but will be too short for the enclosure
Kiwi (NL) | [COMP-ROT-ENC-24W](https://www.kiwi-electronics.nl/Roterende-pulsgever-rotary-encoder-met-drukknop-24-puls?search=encoder) comes with a simple knob

Also, don't forget to order a knob for the encoder, the recommended Bourns encoder would need a “D-shaft” knob.

Retailer | Part number
---|---
Adafruit (US) | [#2055](https://www.adafruit.com/product/2055) is a larger 35mm knob, it won't sit flush with the enclosure but still looks nice
Kiwi (NL) | [ADA-2055](https://www.kiwi-electronics.nl/scrubber-knop-voor-roterende-pulsgever-35mm) is the same 35mm knob from Adafruit
Thonk (UK) | [Davies 1900h clone D-shaft](https://www.thonk.co.uk/shop/1900h-d/)
DJ Tech Tools (US) | [Chroma Caps](https://store.djtechtools.com/products/chroma-caps-knobs-and-faders)

#### Resistors
The “Two Encoders” build will need three resistors, but the two other builds won’t require any. The smaller and very common 1/4 Watt metal film resistors will fit nicely.

Retailer | Part number
---|---
Tayda Electronics (US) | [A-2290](https://www.taydaelectronics.com/resistors/1-4w-metal-film-resistors/resistor-33k-ohm-1-4w-1-metal-film-pkg-of-10.html) for the 33k ohm (×2), and [A-2182](https://www.taydaelectronics.com/resistors/1-4w-metal-film-resistors/10-x-resistor-15k-ohm-1-4w-1-metal-film-pkg-of-10.html) for the 15k ohm (×1)
Mouser | **TK**
Kiwi (NL) | [COMP-RES-25-33K](https://www.kiwi-electronics.nl/Weerstand-33K-ohm-1-4-watt-5-procent-10-stuks) for the 33k ohm (×2), and [COMP-RES-25-15K](https://www.kiwi-electronics.nl/Weerstand-15K-ohm-1-4-watt-5-procent-10-stuks) for the 15k ohm (×1)

#### Enclosure
Plans for a simple enclosure to put it all in are outlined in the [Enclosure](./Enclosure) directory in this repo.

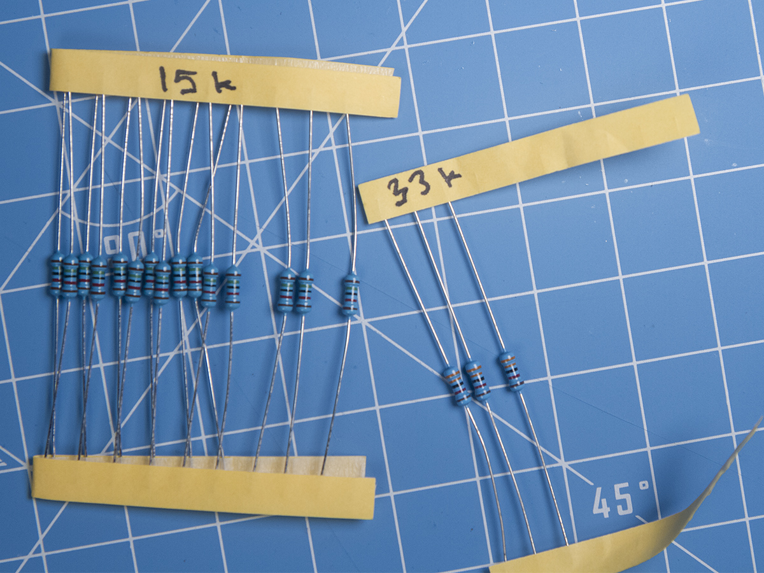
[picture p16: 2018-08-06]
Hardware/buildImages/parts-resistors.jpg

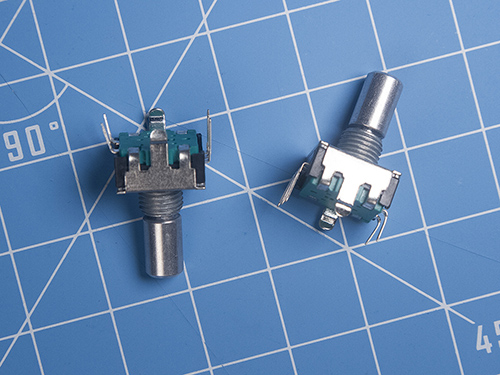
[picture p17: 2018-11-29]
Hardware/buildImages/small/parts-encoders.jpg

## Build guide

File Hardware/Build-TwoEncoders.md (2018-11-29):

# Build Doc — “Two Rotary Encoders” Configuration

minikbd-oshpark-front

## Parts List

Qty | Component | Note
:---:|---|---
1 | Adafruit Trinket M0 | *The black “M0” and not the blue “3V” or “5V” variations of the Trinket*
2 | Rotary Encoders | *2-bit quadrature, with a common footprint from the Bourns PEC11R series*
1 | 33kΩ Resistors | *1/4 watt*
2 | 15kΩ Resistors | *1/4 watt*
— | Various enclosure parts | *Optional but recommended, see notes below*

In this configuration, the only components to add to the circuit board are highlighted below in blue. All other component footprints should be left unpopulated.

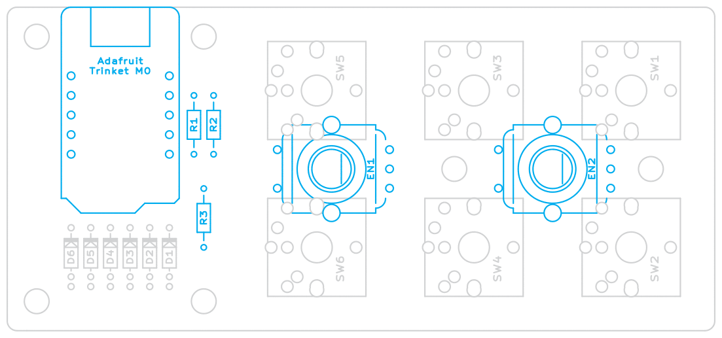
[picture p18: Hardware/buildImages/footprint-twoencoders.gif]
minikbd


### Prepare the Trinket M0

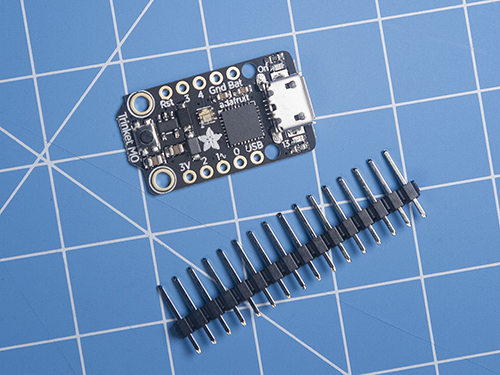
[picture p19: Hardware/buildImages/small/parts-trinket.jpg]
Trinket


- The Trinket M0 comes packaged with a strip of pin headers. Start by clipping the header strip into two smaller sections of five pins. It's okay if there's a small strip of header left over after doing this.

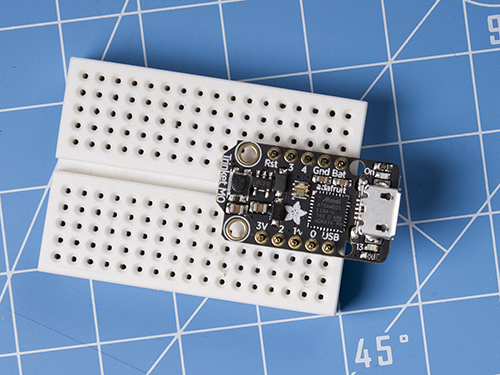
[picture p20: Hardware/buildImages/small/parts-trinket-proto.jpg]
Trinket


- Solder the headers onto the Trinket. It might help to use a small prototyping breadboard to make sure the header pins are aligned upright and not at an angle.

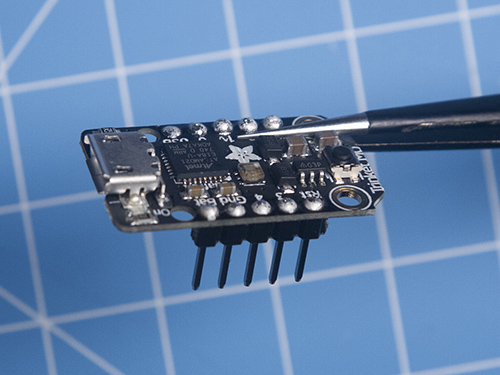
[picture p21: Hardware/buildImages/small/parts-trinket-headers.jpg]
Trinket


- After attaching the headers, you might decide to clean things up a little bit by trimming the freshly soldered pins to be flush with the top of the Trinket board, and rounding off the freshly clipped solder joints by momentarily touching the soldering iron back to the roughly cut pin (as shown)

### Attach the Trinket to the MiniKbd board
- Fit the Trinket to the MiniKbd, being careful to orient the Trinket with its USB port facing out.
- Solder all 10 pins to the back of the MiniKbd, and clip the excess length of the pins flush with the bottom side of the board.

### Solder the resistors

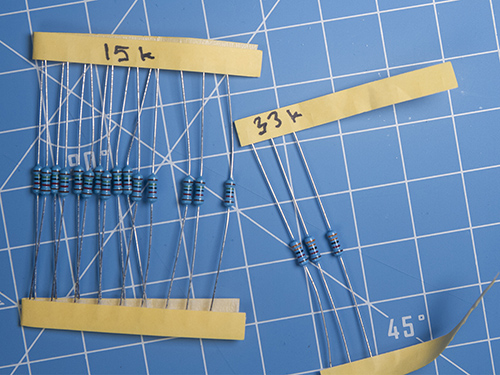
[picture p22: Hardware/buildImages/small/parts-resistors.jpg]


- Three resistors are required to make the pushbuttons on the rotary encoders work.
- Take care to use the correct resistor values, R1 is a 33k resistor, while R2 and R3 are 15k resistors.
- It might help to place all the resistors in their positions and cover them with tape before flipping the board over and soldering, to keep them all neatly aligned.
- After soldering, clip the excess length of the resistor leads flush with the bottom side of the board.

### Add the Rotary Encoders

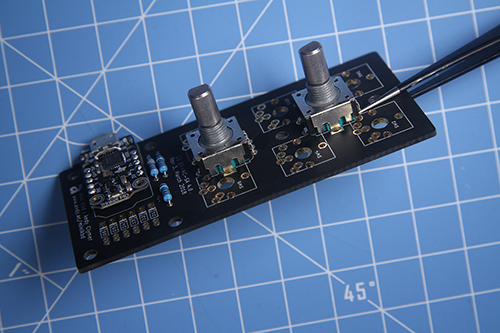
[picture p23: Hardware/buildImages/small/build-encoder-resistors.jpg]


- The rotary encoders have two pins on one side (which connects their pushbutton), three pins on the other side (for the directional signal out of the encoder) and will usually have one more pin on the remaining sides to help hold the encoder firmly to the board.
- If you plan to use an enclosure with holes for the encoder shafts, it might be helpful to fit both encoders into the board and place the top of the enclosure over the shafts before soldering, to ensure that they'll fit properly once they're firmly soldered in place.
- Solder all of the encoder pins on the bottom side of the board, including the side pins that are there for stability. Clip the excess length of the pins to be flush with the board after soldering.

### Cleanup
- At this point the soldering is complete! Double check all of your soldering work to make sure that you didn't accidentally bridge two pins together with a blob of solder, and clip any remaining pins flush with the bottom of the board. If the pins aren't clipped flush with the board, the enclosure may not fit properly.
- Depending on the type of solder used, you may need to clean any remaining "flux" residue on your board. If you used a "no-clean" solder this is still a required step if you don't plan to put the MiniKbd in an enclosure, because after assembly is completely you should avoid coming into contact with the flux residue. Isporopyl alcohol ("rubbing alcohol") on a cotton swab or paper towel should be enough to clean off any residue, just be careful to not saturate the inner workings of your encoders or keyswitches with alcohol.

### Assemble the enclosure, or at least add the feet
- If you plan to use the MiniKbd without an enclosure, you will want to at least apply four rubber feet to the bottom of the board so that it sits firmly on your desktop as you use it, and so that the roughly cut pins on the bottom side don't scratch the surface.
- If you plan to build the recommended laser cut enclosure, have a look at the Enclosure page for assembly instructions.

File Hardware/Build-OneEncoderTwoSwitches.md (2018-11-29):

# Build Doc — “One Rotary Encoder and Two Keyboard Keyswitches” Configuration

minikbd

## Parts List

Qty | Component | Note
:---:|---|---
1 | Adafruit Trinket M0 | *The black “M0” and not the blue “3V” or “5V” variations of the Trinket*
2 | Keyswitches and keycaps | *Cherry MX, Cherry ML or Kailh Low Profile keyswitches will work*
2 | 1N4148 Small Signal Diodes | 
1 | Rotary Encoder | *2-bit quadrature, with a common footprint from the Bourns PEC11R series*
— | Various enclosure parts | *Optional but recommended, see notes below*

In this configuration, the only components to add to the circuit board are highlighted below in blue. All other component footprints should be left unpopulated.

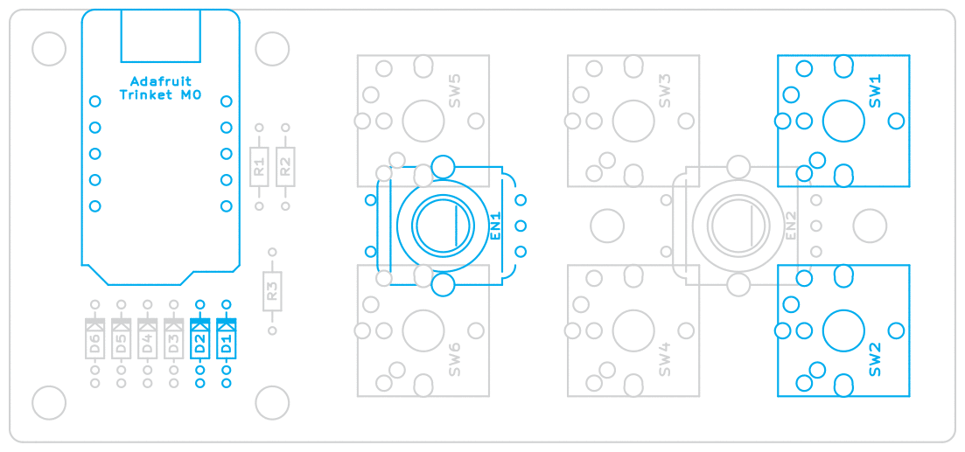
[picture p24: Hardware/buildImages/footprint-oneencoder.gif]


### Solder the diodes

- Each keyswitch is paired up with one diode. Since only two keyswitches are used, you only need to add diodes for "D1" and "D2".
- A diode is a directional component so its orientation on the board does matter. The "cathode" (or, negative) end of the diode will be marked with a contrasting color, usually black or white. It's important that you position the diode so that this stripe is at the same side as the stripe and triangle as marked on the board. 
- The other side of the diode, the "anode" end, can go through either of the two remaining holes on the board. The extra hole is there for diodes that are too long to fit in the smaller set of holes.
- It might help to place all diodes in their positions and cover them with tape before flipping the board over and soldering. This will help keep them all neatly aligned.
- After soldering, clip the excess length of the diode leads flush with the bottom side of the board.

### Prepare the Trinket M0

- The Trinket M0 comes packaged with a strip of pin headers. Start by clipping the header strip into two smaller sections of five pins. It's okay if there's a small strip of header left over after doing this.
- Solder the headers onto the Trinket. It might help to use a small prototyping breadboard to make sure the header pins are aligned upright and not at an angle.
- After attaching the headers, you might decide to clean things up a little bit by trimming the freshly soldered pins to be flush with the top of the Trinket board, and rounding off the freshly clipped solder joints by momentarily touching the soldering iron back to the roughly cut pin (as shown)

### Attach the Trinket to the MiniKbd board

- Fit the Trinket to the MiniKbd, being careful to orient the Trinket with its USB port facing out.
- Solder all 10 pins to the back of the MiniKbd, and clip the excess length of the pins flush with the bottom side of the board.

### Connect the keyswitches
- All of the recommended styles of keyswitches will only have two pins, but you will notice that each position on the MiniKbd was designed to have holes for many popular types of keyswitches. Rotate your keyswitch until it lines up with the holes provided but don't force it if you aren't certain that it's lined up correctly. The recommended "Kailh Low-Profile" switches have two plastic pins which should fit firmly in two support holes on the board, so they might take a little bit of pressure to fit, but only press them in firmly if you're sure the keyswitch pins aren't being forced into the wrong holes.
- If the keyswitch is loose, you may need to temporarily tape it to the board before turning it over and soldering.
- I would recommend soldering only one of the two pins at first, checking to make sure that the keyswitch still appears to be aligned correctly before soldering the second pin.

### Add the Rotary Encoder
- The rotary encoder has two pins on one side (which connects the pushbutton), three pins on the other side (for the directional signal out of the encoder) and will usually have one more pin on the remaining sides to help hold the encoder firmly to the board.
- If you plan to use an enclosure with holes for the encoder shafts, it might be helpful to fit the encoder into the board and place the top of the enclosure over the shaft before soldering, to ensure that they'll fit properly once they're firmly soldered in place.
- Solder all of the encoder pins on the bottom side of the board, including the side pins that are there for stability. Clip the excess length of the pins to be flush with the board after soldering.

### Cleanup
- At this point the soldering is complete! Double check all of your soldering work to make sure that you didn't accidentally bridge two pins together with a blob of solder, and clip any remaining pins flush with the bottom of the board. If the pins aren't clipped flush with the board, the enclosure may not fit properly.
- Depending on the type of solder used, you may need to clean any remaining "flux" residue on your board. If you used a "no-clean" solder this is still a required step if you don't plan to put the MiniKbd in an enclosure, because after assembly is completely you should avoid coming into contact with the flux residue. Isporopyl alcohol ("rubbing alcohol") on a cotton swab or paper towel should be enough to clean off any residue, just be careful to not saturate the inner workings of your encoders or keyswitches with alcohol.

### Assemble the enclosure, or at least add the feet
- If you plan to use the MiniKbd without an enclosure, you will want to at least apply four rubber feet to the bottom of the board so that it sits firmly on your desktop as you use it, and so that the roughly cut pins on the bottom side don't scratch the surface.
- If you plan to build the recommended laser cut enclosure, have a look at the Enclosure page for assembly instructions.

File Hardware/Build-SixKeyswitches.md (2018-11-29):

# Build Doc — “Six Keyboard Keyswitches” Configuration

minikbd-oshpark-front

## Parts List

Qty | Component | Note
:---:|---|---
1 | Adafruit Trinket M0 | *The black “M0” and not the blue “3V” or “5V” variations of the Trinket*
6 | Keyswitches and keycaps | *Cherry MX, Cherry ML or Kailh Low Profile keyswitches will work*
6 | 1N4148 Small Signal Diodes | 
— | Various enclosure parts | *Optional but recommended, see notes below*

In this configuration, the only components to add to the circuit board are highlighted below in blue. All other component footprints should be left unpopulated.

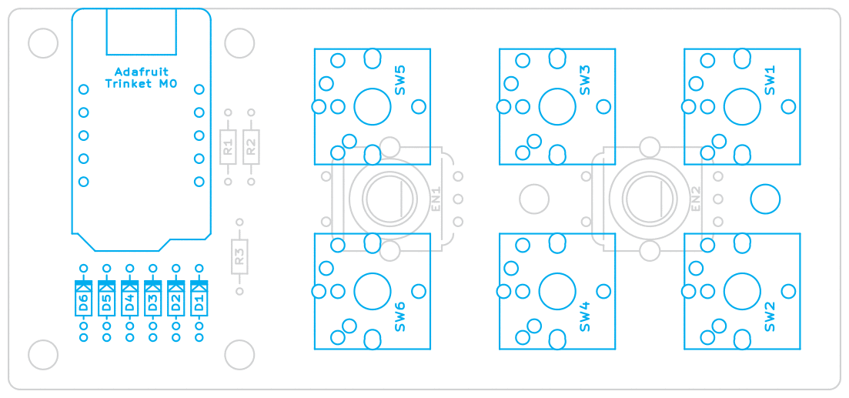
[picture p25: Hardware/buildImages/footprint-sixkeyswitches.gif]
minikbd


### Solder the diodes

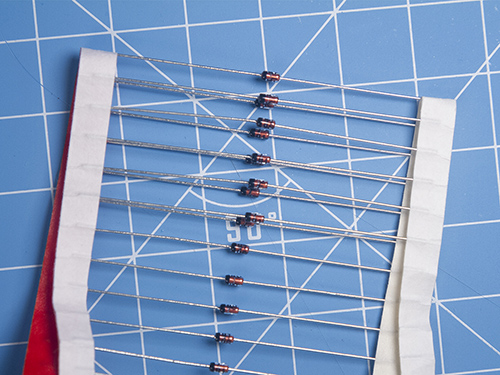
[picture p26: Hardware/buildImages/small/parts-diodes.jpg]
Diodes

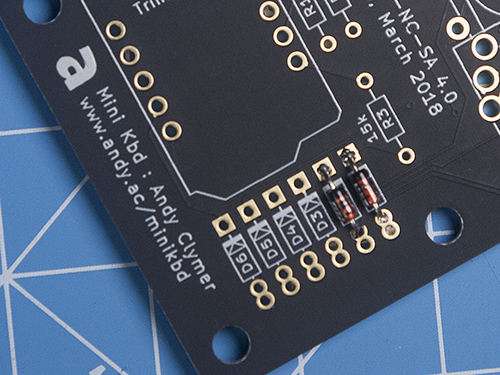
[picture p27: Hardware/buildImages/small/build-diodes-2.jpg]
Diodes


- Each keyswitch is paired up with one diode, so all six diode positions D1 through D6 should be filled.
- A diode is a directional component so its orientation on the board does matter. The "cathode" (or, negative) end of the diode will be marked with a contrasting color, usually black or white. It's important that you position the diode so that this stripe is at the same side as the stripe and triangle as marked on the board. 

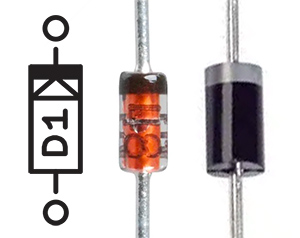
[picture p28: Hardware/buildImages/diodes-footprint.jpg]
Diodes


- The other side of the diode, the "anode" end, can go through either of the two remaining holes on the board. The extra hole is there for diodes that are too long to fit in the smaller set of holes.
- It might help to place all diodes in their positions and cover them with tape before flipping the board over and soldering. This will help keep them all neatly aligned.
- After soldering, clip the excess length of the diode leads flush with the bottom side of the board.

### Prepare the Trinket M0

Trinket

- The Trinket M0 comes packaged with a strip of pin headers. Start by clipping the header strip into two smaller sections of five pins. It's okay if there's a small strip of header left over after doing this.

Trinket

- Solder the headers onto the Trinket. It might help to use a small prototyping breadboard to make sure the header pins are aligned upright and not at an angle.

Trinket

- After attaching the headers, you might decide to clean things up a little bit by trimming the freshly soldered pins to be flush with the top of the Trinket board, and rounding off the freshly clipped solder joints by momentarily touching the soldering iron back to the roughly cut pin (as shown)

### Attach the Trinket to the MiniKbd board

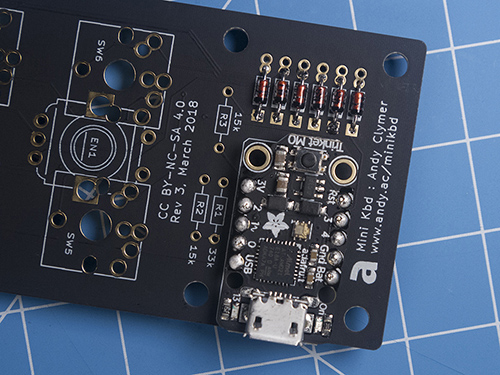
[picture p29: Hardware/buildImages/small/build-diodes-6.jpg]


- Fit the Trinket to the MiniKbd, being careful to orient the Trinket with its USB port facing out.
- Solder all 10 pins to the back of the MiniKbd, and clip the excess length of the pins flush with the bottom side of the board.

### Connect the keyswitches

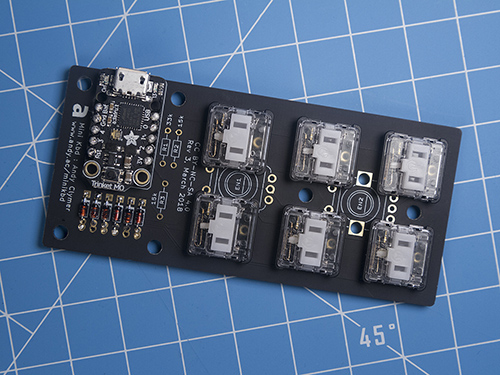
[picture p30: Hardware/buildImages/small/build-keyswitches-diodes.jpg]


- All of the recommended styles of keyswitches will only have two pins, but you will notice that each position on the MiniKbd was designed to have holes for many popular types of keyswitches. Rotate your keyswitch until it lines up with the holes provided but don't force it if you aren't certain that it's lined up correctly. The recommended "Kailh Low-Profile" switches have two plastic pins which should fit firmly in two support holes on the board, so they might take a little bit of pressure to fit, but only press them in firmly if you're sure the keyswitch pins aren't being forced into the wrong holes.
- If the keyswitch is loose, you may need to temporarily tape it to the board before turning it over and soldering.
- I would recommend soldering only one of the two pins at first, checking to make sure that the keyswitch still appears to be aligned correctly before soldering the second pin.

### Cleanup
- At this point the soldering is complete! Double check all of your soldering work to make sure that you didn't accidentally bridge two pins together with a blob of solder, and clip any remaining pins flush with the bottom of the board. If the pins aren't clipped flush with the board, the enclosure may not fit properly.
- Depending on the type of solder used, you may need to clean any remaining "flux" residue on your board. If you used a "no-clean" solder this is still a required step if you don't plan to put the MiniKbd in an enclosure, because after assembly is completely you should avoid coming into contact with the flux residue. Isporopyl alcohol ("rubbing alcohol") on a cotton swab or paper towel should be enough to clean off any residue, just be careful to not saturate the inner workings of your encoders or keyswitches with alcohol.

### Assemble the enclosure, or at least add the feet
- If you plan to use the MiniKbd without an enclosure, you will want to at least apply four rubber feet to the bottom of the board so that it sits firmly on your desktop as you use it, and so that the roughly cut pins on the bottom side don't scratch the surface.
- If you plan to build the recommended laser cut enclosure, have a look at the Enclosure page for assembly instructions.

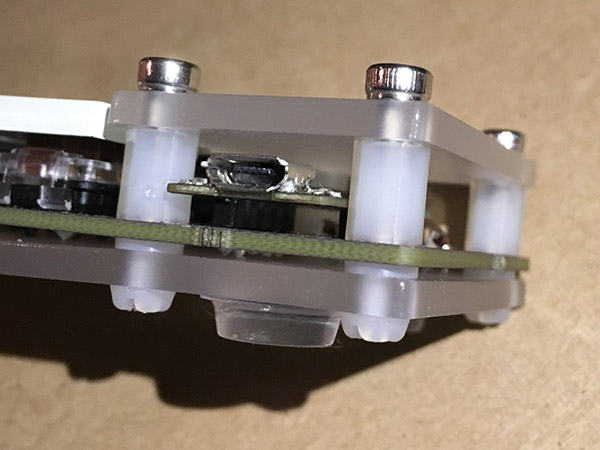
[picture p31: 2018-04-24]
Hardware/Enclosure/buildImages/07-FullStack.jpg

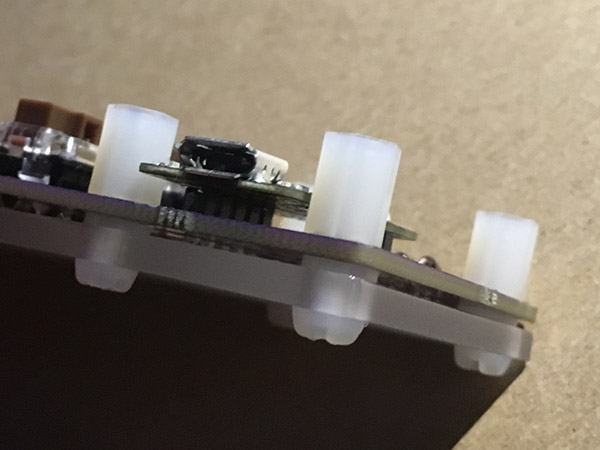
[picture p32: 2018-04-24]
Hardware/Enclosure/buildImages/05-Spacers.jpg

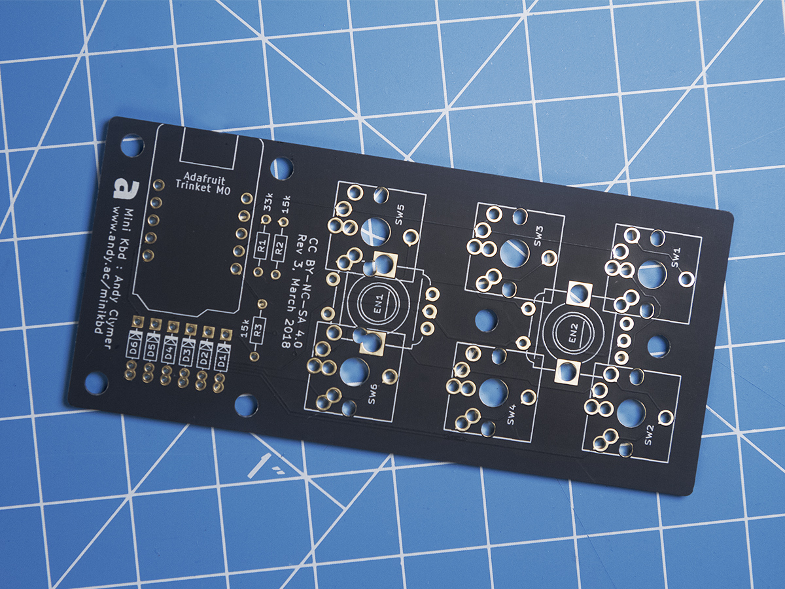
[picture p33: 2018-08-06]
Hardware/buildImages/board.jpg

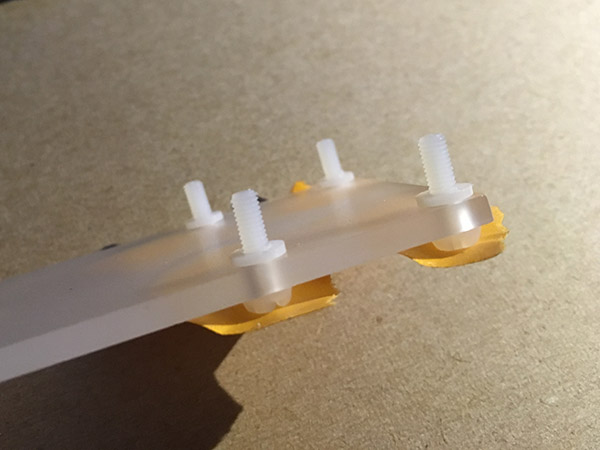
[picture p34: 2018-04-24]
Hardware/Enclosure/buildImages/03-Washers.jpg

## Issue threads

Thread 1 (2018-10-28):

Getting memory allocation error

kglasnapp, 2018-10-28:
I got two of your boards and set one of them up as a 6 key. I tried putting the software on the trinket and I get the output below:

Press any key to enter the REPL. Use CTRL-D to reload.
soft reboot

Auto-reload is on. Simply save files over USB to run them or enter REPL to disable.
main.py output:
Traceback (most recent call last):
  File "main.py", line 8, in <module>
MemoryError: memory allocation failed, allocating %u bytes

I tried it both on Circuit Python 2 and 3.0.3 and they both had the same problem. I am attaching a zip of the circuitpy directory that I used with 3.0.3 to help understand what may be wrong.
[pack.zip](https://github.com/andyclymer/minikbd/files/2522838/pack.zip)

Note: The boards are beautiful

Thanks for your support
Keith Glasnapp

andyclymer, 2018-10-28:
Hi Keith, thanks for building the MiniKbd! I'm sorry you had this problem...

The memory error happens when ``main.py`` tries to import my ButtonMatrix library.

I've built a good number of the six key variety without this problem but I have a thought — is there any chance you're using the device on Windows? I've only tested this configuration on the Mac where it doesn't use the additional Windows driver that comes on the Trinket, so there's a chance that it just exceeds the amount of memory available on the Trinket when it also has to load the additional driver.

My ButtonMatrix library is a little bit over-engineered, it's really built to work with any number of buttons that are set up in a matrix of rows and columns, but this is a little bit overkill for the MiniKbd which will always only be configured with two or six buttons. I'm going to slim the library down just for the MiniKbd to keep its memory usage in line. My six-key build is at my studio space, so I'll update the code tonight and test it when I'm at the studio in the morning. I'll follow back up here once it's all set.

andyclymer, 2018-10-30:
Hi @kglasnapp , I have some updated code that I think should solve this problem. When you have a moment, would you try [the new "Six Key" sample code](https://github.com/andyclymer/minikbd/tree/master/Software/SixKeys-Template)?

The old example used my ``ButtonMatrix`` library which is built to work with any number of buttons, this new sample code instead uses a ``miniKbdButtons`` library which has been pared down by quite a lot. It will use less storage and memory on the Trinket M0, and I hope that this will resolve the problem of the MemoryError you were having.

It's working for me over here, please let me know if it works for you!

Andy

kglasnapp, 2018-10-30:
Thanks – I will give it a try in the morning.

Keith

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

kglasnapp, 2018-10-30:
Thanks so much it worked.

Keith

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

andyclymer, 2018-10-30:
@kglasnapp Great, let me know if you have any other problems or questions!

Closed 2018-10-30.

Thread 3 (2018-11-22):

Images for build documentation & equipment list

jtanadi, 2018-11-22:
Hi! I've been wanting to tinker with hardware for a little while, so this is great.

Couple of things I'm curious about are if you have more images for the build documentation (because I'm afraid of screwing things up) and if you have a recommended equipments list of some sort. I haven't done a lot of (any) builds, so curious about what equipments to start with, etc.

Thanks!

andyclymer, 2018-11-23:
Hi @jtanadi

I do have some step-by-step photos that I took of a recent build, I'll add them to the build docs and let you know by way of this issue once they're all there.

As for the part list, I have part numbers and a buying guide here:
https://github.com/andyclymer/minikbd/blob/master/Hardware/PartsList.md

If you want to build the configuration with the rotary encoders then all of the parts can be purchased conveniently from Adafruit, otherwise there are many options for ordering keyboard keyswitches and keycaps. I like using the low profile keyswitches from Novel Keys which I link to on the [Parts List](https://github.com/andyclymer/minikbd/blob/master/Hardware/PartsList.md) page. Let me know however if anything is unclear with the buying guide for parts.

andyclymer, 2018-11-29:
Hi @jtanadi

I added a few more photos to the build docs, here's one as an example:
https://github.com/andyclymer/minikbd/blob/master/Hardware/Build-SixKeyswitches.md

If you're already going to be ordering a Trinket M0, I think you can trust the soldering irons that Adafruit sells on their own site. If you're new to electronics, pick up a small prototyping breadboard and a starter kit with a few small buttons and sensors. After you're done learning how it works you can attach it to a MiniKbd circuit board.

Andy

jtanadi, 2018-11-29:
Amazing. Thanks so much!

Closed 2018-11-29.

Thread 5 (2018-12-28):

Two-encoder multimode not working due to missing lib files. How do I reset cirtcuitpy?

thundernixon, 2018-12-28:
I've successfully set up a 6-key MiniKbd and I'm now working on the two-encoder version.

~~I am able to get this working with the `main.py` of the [Two-Encoder Keyboard](https://github.com/andyclymer/minikbd/tree/master/Software/TwoEncoder-Keyboard) configuration, but when I upload the `main.py` of the [Two Encoder Multimode](https://github.com/andyclymer/minikbd/tree/master/Software/TwoEncoder-Multimode) configuration, input is no longer registering.~~

~~I am trying to detect input with the [suggested terminal serial console](https://learn.adafruit.com/welcome-to-circuitpython/advanced-serial-console-on-mac-and-linux)~~

Actually, I'm now seeing that the input is triggered by `print` statements like `print("enc-1-up")` in the `main.py`. However, this has led into another error when I refresh the serial console:

```
Traceback (most recent call last):
  File "main.py", line 4, in <module>
ImportError: no module named 'adafruit_hid.consumer_control'
```

I see that there are lib files available such as [consumer_control_code](https://circuitpython.readthedocs.io/projects/hid/en/latest/_modules/adafruit_hid/consumer_control_code.html). I took the step (which I now see wasn't the best idea) of trying to reset my trinket m0, thinking that it must need the newer version. This has led me down a bit of a rabbithole.

I've tried to reset the trinket with the [Adafruit instructions here](https://learn.adafruit.com/adafruit-trinket-m0-circuitpython-arduino/circuitpython). However, I'm now unable to copy over the basic files.

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

I suspect that this may be due to my inability to delete the `.trashes` folder.

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

I'll keep troubleshooting this and update here when I solve it. However, if anyone knows of any easy way to solve this, I'd appreciate some pointers!

(As a sidenote, it may be useful to include something in the files or in the readme of the multimode software about adding the necessary extra lib files).

thundernixon, 2018-12-28:
I have found that it's simple to delete hidden files if I open CIRCUITPY in VS Code.

However, I am now trying to add in the correct `.mpy` files, but I get a "Not enough disk space" error:

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

thundernixon, 2018-12-29:
Wow, that space really _is_ limited! The adafruit troubleshooting link you provided is very helpful, however. Thanks!

I was able to successfully delete everything via the terminal commands and start again, adding from files from the working other MiniKbd. However, I was getting an error:

andyclymer, 2018-12-30:
Yeah, the space is super limited. I think my next project will use the Adafruit ItsyBitsy or Feather which have a extra 265k of storage, which is massive in comparison :)

You're learning some good lessons with this project! And I'm learning what I need to update in the docs. If you upgraded to CircuitPython 4 on your Trinket, then as you found you do need to update all of the mpy files for version 4. I keep that `Adafruit_CircuitPython_Bundle` folder handy on my computer and only copy over the mpy files that I need at the moment.

Glad to see that it worked after you made that switch! I'll leave this issue open until I update the docs with a recommendation (but it will be pretty much exactly what you've done)

thundernixon, 2019-02-23:
Ran into this again today, and https://learn.adafruit.com/welcome-to-circuitpython/troubleshooting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 really helped, particularly the steps shown on using the terminal to prevent metadata files and to copy over files without making new metadata files.

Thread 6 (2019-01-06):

Is there a way to "debounce" the button pushes on a two-encoder setup?

thundernixon, 2019-01-06:
I'm using the two-mode setup for the two-encoder, and I love it!

One mode uses the music control configuration: play/pause, prev/next, & volume.

The other mode is setup to control video via the fantastic [Video Speed Controller](https://github.com/igrigorik/videospeed) chrome extension: play/pause, faster/slower skip-forward/backward.

However, in both cases, I have some problems around play/pause input, which I have attached to an encoder press. My best guess is that this is due to a lack of [debouncing](https://www.maximintegrated.com/en/glossary/definitions.mvp/term/debounce/gpk/82) on the button press – so each press is actually captured as many presses, and this confuses most play/pause controls.

I wanted to test/show this theory, so I made [a Codepen that responds to keypresses](https://codepen.io/thundernixon/pen/WLJwBd). In the gif below, I touch my real spacebar three times, and then I press the MiniKbd encoder a couple of times. It shows that the MiniKbd input is actually registered as many key presses, which is probably what is messing this up for YouTube controls, etc, currently.

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

Is there any good way to debounce key input from these controllers? If so, it would make the button presses quite a bit more useful. Thanks for any tips!

andyclymer, 2019-01-06:
Yeah, if you need to denounce the button you can see a lazy way that I did it in this example with the fastTurn function:

https://github.com/andyclymer/minikbd/blob/master/Software/TwoEncoder-VolumeControl/main.py

I say it’s lazy because it limits all button presses and not just a repeated press on the same button. But maybe this is a good starting point?

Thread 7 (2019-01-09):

Ponoko rejects the Ponoko files

timkingman, 2019-01-09:
I tried to upload Ponoko-MiniKbd-SixKeys.eps to Ponoko, and I got a "Blue Alert" error:
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

"Fix this right now" links to https://ponoko.zendesk.com/hc/en-us/community/posts/210090228-File-won-t-upload-says-Oops-Blue-Alert-

I'm not in enough of a hurry to ask Ponoko support for help, but my soldering buddy might have Illustrator, so I'll see if I can figure out a fix and submit a PR.

andyclymer, 2019-01-09:
Ah! That must be my mistake, thanks for bringing it to my attention. I’m traveling right now and am away from the computer for a little while, but if you’re able to change the color and submit a PR that would be great.

The “AllThree” file should work, I had a couple copies made of that one from Ponoko to test out the service.

JoshApos, 2019-08-19:
Just commenting to confirm that the 'AllThree' file worked as of August '19.

I won't receive the pieces being cut for another few weeks, but I received confirmation that the files were accepted and the order was being made.

andyclymer, 2019-08-21:
Hi @timkingman and @JoshApos ,

My mistake for missing this issue when it was posted months ago, but it looks like there was a problem with two of the files. I fixed them and can confirm that all of the Ponoko laser files do properly upload now. Thanks for calling this to my attention!

Closed 2019-09-16.

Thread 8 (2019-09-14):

Writing a string does not work with a single button press

Charlie22911, 2019-09-14:
Working on my first project involving any degree of code, and also my first github post; I'm looking to use this as way to insert strings with a single button press (for example, game server commands).
Using "kbdLayout.write('This is a test!')" for example causes it to insert that string when the trinket boots, and subsequently locks up on the next button press.

Using Mu serial monitor I see:

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

I'm not really sure how to approach this, any help would be appreciated.

andyclymer, 2019-09-16:
Hi @Charlie22911 !

First, I wonder if you're using any of the example code from this repo? It sounds like maybe you're using the "SixKeys-Template" code? Did you modify the main.py file? If you made any changes, could you paste it into a comment here so that I can have a closer look at what might be going on?

The error is pointing to line 28 in the `main.py` file, if you're using the "SixKeys-Template" this is the line that turns a `buttonID` number into a keycode command by checking the `buttonIDtoKeycode` dictionary, and then it tells the device to type that keycode with the `kbd.press()` function.

If you changed this line, or if you added more than just a keycode in the `buttonIDtoKeycode` dictionary (like, is this where you added your entire string?) then some other lines might need to change too. But let's start by having a look at your `main.py` script if you can paste it in here.

Andy

Charlie22911, 2019-10-06:
Apologies for the delay, I was preoccupied with the wonderful kit from Tindie.
Yes, I am using the example code here; specifically the six keys code.

 The specific change that breaks things is changing line 19 to:
`    1: kbdLayout.write('string'),`

Here is main.py as it sits on my trinket now:

`import board
from digitalio import DigitalInOut, Direction, Pull
import adafruit_dotstar as dotstar
from adafruit_hid.keyboard import Keyboard
from adafruit_hid.keycode import Keycode
from adafruit_hid.keyboard_layout_us import KeyboardLayoutUS

from miniKbdButtons import MiniKbdButtons

dot = dotstar.DotStar(board.APA102_SCK, board.APA102_MOSI, 1, brightness=0.5)
dot[0] = (0, 0, 0)

kbd = Keyboard()
kbdLayout = KeyboardLayoutUS(kbd)

# Customize these keycodes
# https://circuitpython.readthedocs.io/projects/hid/en/latest/api.html#adafruit-hid-keycode-keycode
buttonIDtoKeycode = {
    1: kbdLayout.write('string'),
    2: Keycode.TWO,
    3: Keycode.THREE,
    4: Keycode.FOUR,
    5: Keycode.FIVE,
    6: Keycode.SIX}

def buttonDownCallback(buttonID, othersDown):
    kbd.press(buttonIDtoKeycode[buttonID])
    print('Button ' + str(buttonID) + ' is pressed. ' + str(othersDown))

def buttonUpCallback(buttonID):
    kbd.release(buttonIDtoKeycode[buttonID])
    print('Button ' + str(buttonID) + ' is released.')

ButtonMatrix = MiniKbdButtons(
    keyDownCallback=buttonDownCallback,
    keyUpCallback=buttonUpCallback)

# Main Loop
while True:
    ButtonMatrix.update()`

I've made other superficial changes to help get a grasp at whats going on, but I don't think they are responsible. miniKbdButtons.py is unchanged.
I really appreciate the help Andy!

Charlie22911, 2019-10-06:
I got things working, but not in the way I expected. I cobbled together bits of arduino code from various sources online. I think I'd rather figure out how to make it work in circuit python since I haven't accomplished my goal by such "cheating". Here is the relevant code, I'm sure its a horror show (not that I'd know):

```
#include "Adafruit_Keypad.h"
#include "Keyboard.h"

const byte ROWS = 2;
const byte COLS = 3;
char keys[ROWS][COLS] = {
  {'1','2','3'},
  {'4','5','6'}
};
byte rowPins[ROWS] = {0, 1};
byte colPins[COLS] = {3, 4, 2};

Adafruit_Keypad customKeypad = Adafruit_Keypad( makeKeymap(keys), rowPins, colPins, ROWS, COLS);

long lastDebounceTime = 0;
long debounceDelay = 50;

void setup() {
  customKeypad.begin();
}

void loop() {
  customKeypad.tick();

  if ( (millis() - lastDebounceTime) > debounceDelay) {

    while(customKeypad.available()){
      keypadEvent e = customKeypad.read();

      if ((e.bit.KEY == '1') && (e.bit.EVENT == KEY_JUST_PRESSED)){
        Keyboard.println("This key is TOP LEFT");
        lastDebounceTime = millis();
      }

      else if ((e.bit.KEY == '2') && (e.bit.EVENT == KEY_JUST_PRESSED)){
        Keyboard.println("This key is TOP MIDDLE");
        lastDebounceTime = millis();
      }

      else if ((e.bit.KEY == '3') && (e.bit.EVENT == KEY_JUST_PRESSED)){
        Keyboard.println("This key is TOP RIGHT");
        lastDebounceTime = millis();
      }

      else if ((e.bit.KEY == '4') && (e.bit.EVENT == KEY_JUST_PRESSED)){
        Keyboard.println("This key is BOTTOM LEFT");
        lastDebounceTime = millis();
      }

      else if ((e.bit.KEY == '5') && (e.bit.EVENT == KEY_JUST_PRESSED)){
        Keyboard.println("This key is BOTTOM MIDDLE");
        lastDebounceTime = millis();
      }

      else if ((e.bit.KEY == '6') && (e.bit.EVENT == KEY_JUST_PRESSED)){
        Keyboard.println("This key is BOTTOM RIGHT");
        lastDebounceTime = millis();
      }
    }
  }
}
```

andyclymer, 2019-10-06:
HI @Charlie22911 ,

Thanks for posting your code, let me walk you through what's happening. From your Python traceback, the error can be found on line 28 in your main.py:

`kbd.press(buttonIDtoKeycode[buttonID])`

The `kbd` object has a method called `press()` which is expecting a single keycode. In one line, it takes the `buttonID` from the key, uses it as a keyword in teh `buttonIDtoKeycode` dictionary to fetch the keycode assigned to this key, and then passes the result as an argument in the `kbd.press()` method.

For this to work, all of the values in the dictionary should only be single keycodes. But I see on line 19 you changed the entry for ID 1 to `kbdLayout.write('string')` and this is the problem.

If you want to assign actions to the keys as a dictionary of strings instead of a dictionary of keycodes, then let me point you in the right direction. First, change all of the values in the `buttonIDtoKeycode` dictionary into strings, but without the `kbdLayout.write()` part:

```
buttonIDtoKeycode = {
    1: 'string',
    2: 'hello',
    3: 'asdf',
    4: 'another string',
    5: 'etc',
    6: 'etc'}
```

...and then change the callback on line 28 to write the string that it fetches from the dictionary instead of pressing a single key. This is where you'll use the `kbdLayout.write()`

```
def buttonDownCallback(buttonID, othersDown):
    kbdLayout.write(buttonIDtoKeycode[buttonID])
```

This is untested but it should work, I hope it makes sense what's going on. But if not let me know and I can go into a little bit more depth!

Charlie22911, 2019-10-07:
Thank you for the quick reply, making the suggested changed results in the following:

```
Traceback (most recent call last):
  File "main.py", line 42, in <module>
  File "miniKbdButtons.py", line 53, in update
  File "main.py", line 28, in buttonDownCallback
  File "adafruit_hid/keyboard_layout_us.py", line 209, in write
TypeError: 'int' object is not iterable
```

Could this have something to do with the function that releases the keys after being pressed, being that a string is not a key? main.py below:

```
import board
from digitalio import DigitalInOut, Direction, Pull
import adafruit_dotstar as dotstar
from adafruit_hid.keyboard import Keyboard
from adafruit_hid.keycode import Keycode
from adafruit_hid.keyboard_layout_us import KeyboardLayoutUS

from miniKbdButtons import MiniKbdButtons

dot = dotstar.DotStar(board.APA102_SCK, board.APA102_MOSI, 1, brightness=0.2)
dot[0] = (0, 0, 0)

kbd = Keyboard()
kbdLayout = KeyboardLayoutUS(kbd)

# Customize these keycodes
# https://circuitpython.readthedocs.io/projects/hid/en/latest/api.html#adafruit-hid-keycode-keycode
buttonIDtoKeycode = {
	1: 'This is a test',
	2: Keycode.TWO,
	3: Keycode.THREE,
	4: Keycode.FOUR,
	5: Keycode.FIVE,
	6: Keycode.SIX}

def buttonDownCallback(buttonID, othersDown):
    kbdLayout.write(buttonIDtoKeycode[buttonID])
    print('Button ' + str(buttonID) + ' is pressed. ' + str(othersDown))

def buttonUpCallback(buttonID):
    kbd.release(buttonIDtoKeycode[buttonID])
    print('Button ' + str(buttonID) + ' is released.')

ButtonMatrix = MiniKbdButtons(
	keyDownCallback=buttonDownCallback,
	keyUpCallback=buttonUpCallback)

# Main Loop
while True:
	ButtonMatrix.update()
```

andyclymer, 2019-10-07:
Ah yes! I knew I should have tested my reply before sending it but I didn't have a MiniKbd on hand at the moment.

In CircuitPython, the keyboard can work in two ways — you can press and hold keys and then release them, or you can have it write a string to type it out character by character. Since you've switched to writing strings, you can remove line 32, the line with the `kbd.release()` function call.

Adafruit's [demo code for the HID Keyboard module](https://learn.adafruit.com/adafruit-circuit-playground-express/circuitpython-hid-keyboard) has an interesting solution where it uses a condition between lines 57 and 61 where it chooses to `write` if the variable `k` is a string (which in your case would be what's returned from the `buttonIDtoKeycode[buttonID]` dictionary call and not the variable `k`), otherwise it will assume that it was a keycode and it will press and then release the keys. This is something you might be able to try if you still want to mix strings and keycodes in the `buttonIDtoKeycode` dictionary.

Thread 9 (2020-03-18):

CircuitPython code crashes on newest versions of CP and hid library

FoamyGuy, 2020-03-18:
```
Traceback (most recent call last):
  File "main.py", line 13, in <module>
TypeError: function takes 2 positional arguments but 1 were given
```

This error is due to a slight change in the `adafruit_hid` library, it now needs to be passed a parameter in it's constructor.

andyclymer, 2020-03-24:
Thank you for these! I'm traveling right now and don't have a MiniKbd on hand (if you can believe it), but the changes look good. I'll merge and leave a note that the example scripts are for CircuitPython version 4 and above. Thank you again!

Closed 2020-03-24.

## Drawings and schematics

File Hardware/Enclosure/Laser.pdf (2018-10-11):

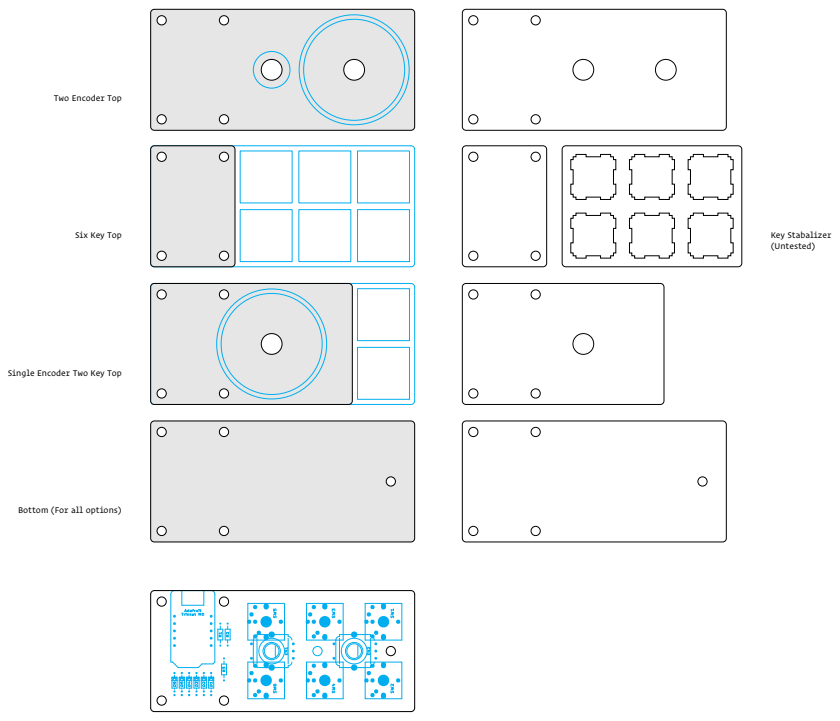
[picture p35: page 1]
Six Key Top; Key Stabalizer; (Untested)

Two Encoder Top

Single Encoder Two Key Top

Bottom (For all options)

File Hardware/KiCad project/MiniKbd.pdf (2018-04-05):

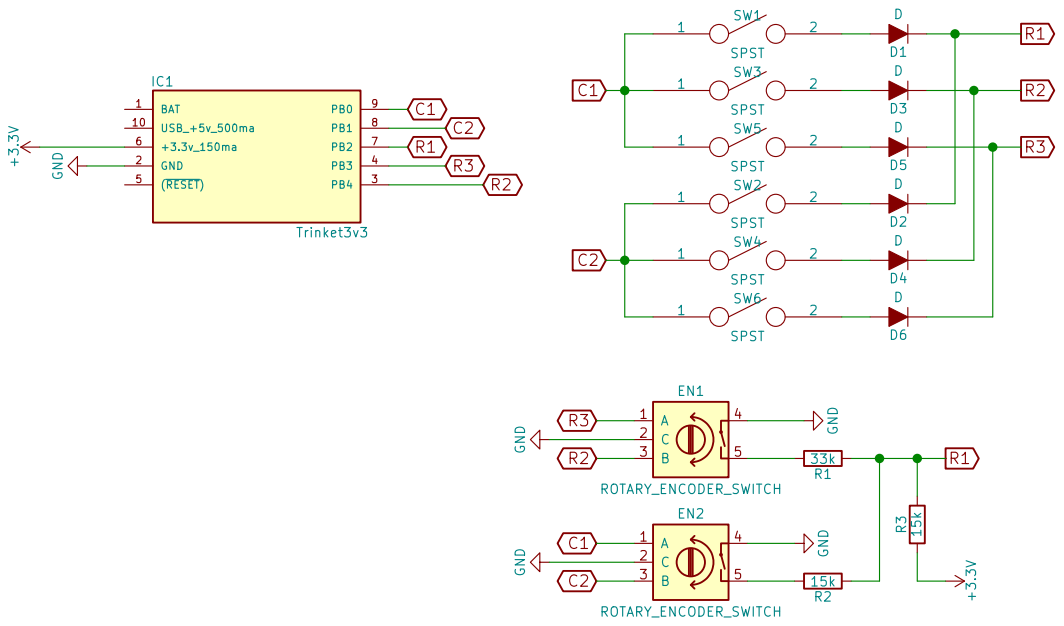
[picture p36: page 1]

Id: 1/1 Title: File: MiniKbd.sch Sheet: /

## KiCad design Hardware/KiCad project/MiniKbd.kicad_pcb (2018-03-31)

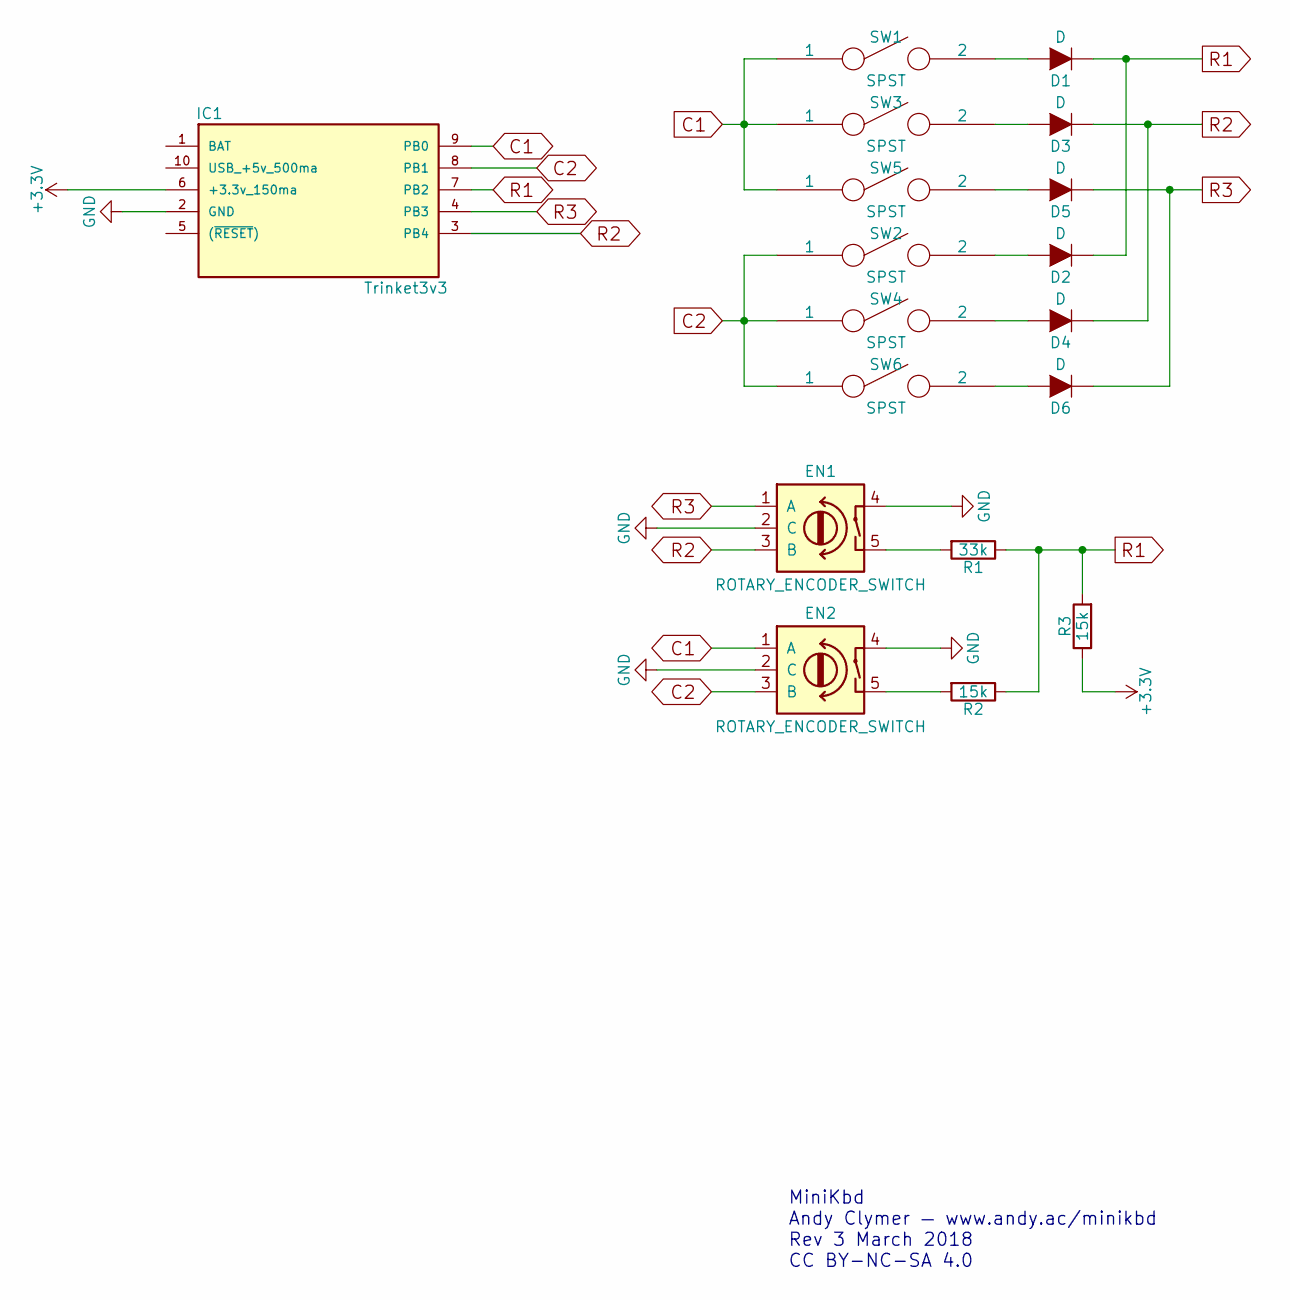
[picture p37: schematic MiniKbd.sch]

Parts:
D1, D2, D3, D4, D5, D6: D; Diode_SmallDualSize
EN1, EN2: ROTARY_ENCODER_SWITCH; Encoder_Bourns_PEC11_12mm_123
IC1: Trinket3v3; Trinket_3v3
R1: 33k; R_Axial_DIN0204_L3.6mm_D1.6mm_P7.62mm_Horizontal
R2, R3: 15k; R_Axial_DIN0204_L3.6mm_D1.6mm_P7.62mm_Horizontal
SW1, SW2, SW3, SW4, SW5, SW6: SPST; CHERRY_MXML_KAILH_PCB_100H

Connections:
+3V3: IC1.6 (+3.3v_150ma), R3.1
C1: EN2.1 (A), IC1.9 (PB0), SW1.1, SW3.1, SW5.1
C2: EN2.3 (B), IC1.8 (PB1), SW2.1, SW4.1, SW6.1
GND: EN1.2 (C), EN1.4, EN2.2 (C), EN2.4, IC1.2 (GND)
unnamed: D1.2 (A), SW1.2
unnamed: D2.2 (A), SW2.2
unnamed: D3.2 (A), SW3.2
unnamed: D4.2 (A), SW4.2
unnamed: D5.2 (A), SW5.2
unnamed: D6.2 (A), SW6.2
unnamed: EN1.5, R1.2
unnamed: EN2.5, R2.2
R1: D1.1 (K), D2.1 (K), IC1.7 (PB2), R1.1, R2.1, R3.2
R2: D3.1 (K), D4.1 (K), EN1.3 (B), IC1.3 (PB4)
R3: D5.1 (K), D6.1 (K), EN1.1 (A), IC1.4 (PB3)

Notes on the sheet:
MiniKbd Andy Clymer — www.andy.ac/minikbd Rev 3 March 2018 CC BY-NC-SA 4.0

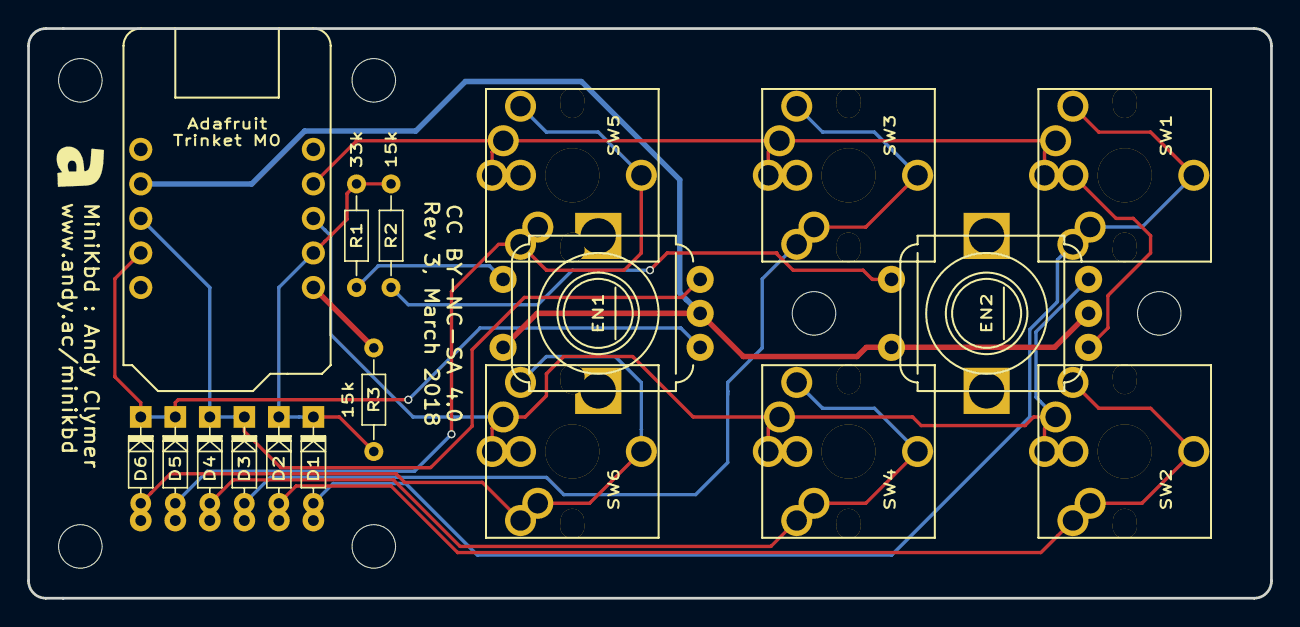
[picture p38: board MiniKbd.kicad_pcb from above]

Board: 2 copper layers, 91.4 x 41.9 mm, 18 parts (0 on the bottom side), 15 nets.

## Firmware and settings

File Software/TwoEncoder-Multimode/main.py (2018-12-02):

import board
from adafruit_hid.keyboard import Keyboard
from adafruit_hid.keycode import Keycode
from adafruit_hid.consumer_control import ConsumerControl
from adafruit_hid.consumer_control_code import ConsumerControlCode
import adafruit_dotstar as dotstar
from digitalio import DigitalInOut, Direction, Pull
from analogio import AnalogIn
from encoder import Encoder
import time
import random

kbd = Keyboard()
cc = ConsumerControl()
dot = dotstar.DotStar(board.APA102_SCK, board.APA102_MOSI, 1, brightness=0.5)

modeColors = [(0, 255, 128), (255, 0, 0)]
mode = 0
dot[0] = modeColors[0]

prevTurn = time.monotonic()
def fastTurn():
	global prevTurn
	now = time.monotonic()
	diff = now - prevTurn
	prevTurn = now
	if diff < 0.1:
		return True
	return False
	


def enc1Up():
	global mode
	if mode == 0:
		cc.send(ConsumerControlCode.SCAN_NEXT_TRACK)
	elif mode == 1:
		kbd.press(Keycode.Z)
	kbd.release_all()

def enc1Down():
	global mode
	if mode == 0:
		cc.send(ConsumerControlCode.SCAN_PREVIOUS_TRACK)
	elif mode == 1:
		kbd.press(Keycode.X)
	kbd.release_all()

def enc2Up():
	global mode
	if mode == 0:
		if not fastTurn():
			kbd.press(Keycode.ALT)
			kbd.press(Keycode.SHIFT)
		cc.send(ConsumerControlCode.VOLUME_INCREMENT)
	elif mode == 1:
		kbd.press(Keycode.RIGHT_BRACKET)
	kbd.release_all()

def enc2Down():
	global mode
	if mode == 0:
		if not fastTurn():
			kbd.press(Keycode.ALT)
			kbd.press(Keycode.SHIFT)
		cc.send(ConsumerControlCode.VOLUME_DECREMENT)
	elif mode == 1:
		kbd.press(Keycode.LEFT_BRACKET)
	kbd.release_all()

def button1():
	global mode
	if not fastTurn():
		mode += 1
		if mode >= len(modeColors):
			mode = 0
		dot[0] = modeColors[mode]

def button2():
	global mode
	if mode == 0:
		if not fastTurn():
			cc.send(ConsumerControlCode.PLAY_PAUSE)
	if mode == 1:
			kbd.press(Keycode.GUI)
			kbd.press(Keycode.ZERO)
	kbd.release_all()


e1 = Encoder(board.D4, board.D3, upCallback=enc1Up, downCallback=enc1Down)
e2 = Encoder(board.D1, board.D0, upCallback=enc2Up, downCallback=enc2Down)

buttonPin = AnalogIn(board.D2)


while True:
	
	e1.update()
	e2.update()

	v = buttonPin.value
	if 65535 > v > 54500:
		b1 = False
		b2 = False
	elif 54500 > v > 38500:
		b1 = True
		b2 = False
	elif 38500 > v > 29400:
		b1 = False
		b2 = True
	elif v < 29400:
		b1 = True
		b2 = True

	if b1:
		button1()
	if b2:
		button2()

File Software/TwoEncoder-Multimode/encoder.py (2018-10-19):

from digitalio import DigitalInOut, Direction, Pull

class Encoder:
	
	"""
	CircuitPython Rotary Encoder (without interrupts)
	2017_10_16 Andy Clymer
	"""
	
	def __init__(self, pin1, pin2, upCallback=None, downCallback=None):
		# Init pins
		self.d1 = DigitalInOut(pin1)
		self.d1.direction = Direction.INPUT
		self.d1.pull = Pull.UP
		self.d2 = DigitalInOut(pin2)
		self.d2.direction = Direction.INPUT
		self.d2.pull = Pull.UP
		# Callbacks
		self.upCallback = upCallback
		self.downCallback = downCallback
		# Values for comparison
		self.prev1 = 0
		self.prev2 = 0
		self.new1 = 0
		self.new2 = 0
		self.lastFewDirs = [0, 0, 0, 0]
		# Encoder truth table
		self.encTable = {
			(1, 1): {(1, 0):1, (1, 1):0, (0, 1):-1, (0, 0):2},
			(1, 0): {(0, 0):1, (1, 0):0, (1, 1):-1, (0, 1):2},
			(0, 0): {(0, 1):1, (0, 0):0, (1, 0):-1, (1, 1):2},
			(0, 1): {(1, 1):1, (0, 1):0, (0, 0):-1, (1, 0):2}}
	
	def update(self):
		self.new1 = self.d1.value
		self.new2 = self.d2.value
		# Pin values changed:
		if not (self.prev1, self.prev2) == (self.new1, self.new2):
			# Determine out the dirction
			newDir = self.encTable[(self.prev1, self.prev2)][(self.new1, self.new2)]
			self.prev1 = self.new1
			self.prev2 = self.new2
			# Hold on to this new direction with the last three
			self.lastFewDirs = self.lastFewDirs[1:] + [newDir]
			# A good reading has four values of the same direction.
			# If the list adds up as expected, return the direction and rest the list
			s = sum(self.lastFewDirs)
			if s == 4:
				self.lastFewDirs = [0, 0, 0, 0]
				if self.upCallback: self.upCallback()
			elif s == -4:
				self.lastFewDirs = [0, 0, 0, 0]
				if self.downCallback: self.downCallback()
		return None

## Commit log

2018-03-31 Updated .gitignore to include Python and KiCad files
2018-03-31 First commit of the hardware and general repo layout
    [MiniKbd.kicad_pcb, MiniKbd.sch]
2018-04-01 Adding enclosure laser files
2018-04-05 Updated the enclosure art
2018-04-05 Moving files to the KiCad Project folder
    [MiniKbd.kicad_pcb, MiniKbd.sch]
2018-04-05 Added schematic PDF
    [MiniKbd.sch]
2018-04-05 Folder rename
    [MiniKbd.kicad_pcb, MiniKbd.sch]
2018-04-24 Adding enclosure build images
2018-08-07 Adding more enclosure images
2018-08-18 Adds an untested key stabalizer to the laser enclosure PDF
2018-10-11 Adding sample code
2018-10-19 Adding sample code for the encoder with two keys
2018-10-19 Replaced spaces with tabs for consistency
    [buttonMatrix.py, encoder.py]
2018-10-24 Making some new sample code, and renaming some others
2018-10-30 Finishing up work on the simplified button matrix code
2018-11-17 Changing a pin name from A1 to D2 for compatibility with older versions of CircuitPython
2018-11-27 Fixing pin numbers in the TwoEncoder-Volume example
    [main.py]
2018-11-27 Updating the pin numbers in the TwoEncoder-Keyboard example
2018-11-27 Fixing pin numbers
2018-11-30 Adding a delay for the encoder button pressing
2018-11-30 Adding an example with the encoders to have more than one mode
2019-08-21 Updating two of the ponoko laser files to fix upload problems to ponoko.com
